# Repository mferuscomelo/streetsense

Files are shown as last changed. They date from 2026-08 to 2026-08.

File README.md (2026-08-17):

# StreetSense

*A submission for Hackster.io's [Modern Java in the Wild](https://www.hackster.io/contests/modern-java-in-the-wild) contest, sponsored by Avnet and Oracle.*

Know what you're breathing, everywhere you go, not just at home.

StreetSense demo video (https://youtu.be/7NOgXHcya4o)

## The story

### Why I built this

My apartment is thoroughly instrumented. Every room ties into my Home
Assistant setup, so I can tell you the CO2 level in my kitchen or the
humidity in my bedroom without thinking twice about it. It's a small
obsession of mine, but it means I always know exactly how good, or bad, the
air around me actually is.

Then I step outside for a run or a bike ride, and all of that knowledge just
disappears. I have no idea what I'm actually breathing, or how loud the
street I'm running down really is. A couple of my cycling friends have asked
me some version of "is it actually worth exercising outside today," and none
of us have ever had a real answer, just a weather app and a shrug.

I'm studying electrical engineering, so instead of leaving it at that, I
decided to build the answer myself. That's StreetSense: a sensor node small
enough to clip on before a run, paired with a phone that already goes
everywhere with you anyway.

### How it works

The sensor node measures particulate matter, volatile organic compounds, and
noise, once a second, and streams it to your phone over Bluetooth. You tag
the outing as a run, a ride, or a walk, and the app carries it through what I
call a session.

The interesting part isn't the raw numbers. Nobody thinks in micrograms per
cubic meter. So the backend turns a session into a dose: not "the air was 34
µg/m³ of PM2.5" but "you inhaled 0.6 mg of it, and the worst 30 seconds was
that one junction." It weighs the reading by how hard you were probably
breathing, since a jog through mediocre air costs you more than a walk
through the same air. Sessions stack up over time, so you can compare this
route against that one, or this morning against last week.

None of this needs your exact location. The app rounds every reading to a
grid cell about 110 meters wide before it sends anything, and your real
route never leaves your phone.

## System architecture

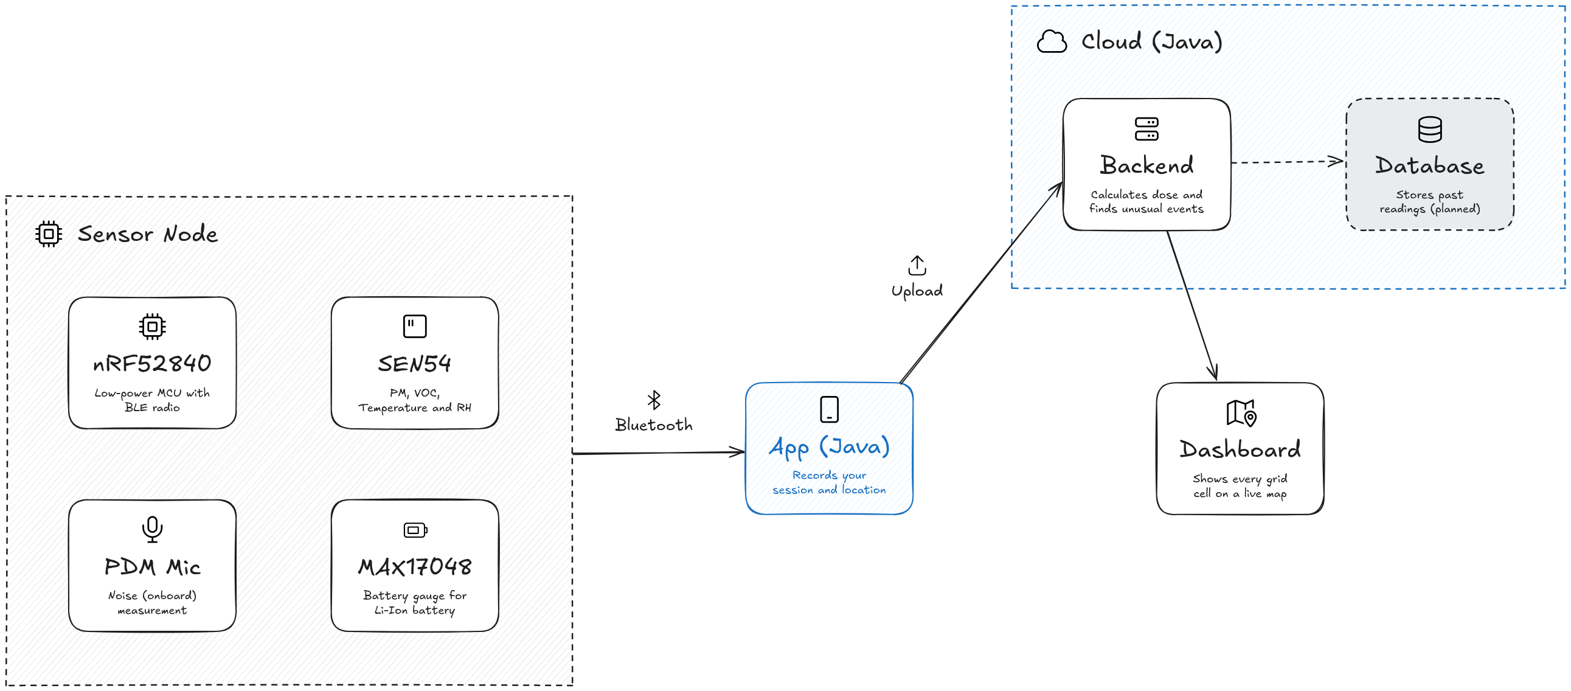
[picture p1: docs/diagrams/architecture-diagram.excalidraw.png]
StreetSense system architecture


StreetSense has four parts, and each one has exactly one job: the sensor
node measures, the app carries a session and protects your location, the
backend turns a reading into a dose and a verdict, and the dashboard shows
the crowd layer live. Each is broken out below with the specific hardware,
the communication protocols, and the reasoning behind each choice.

## Sensor node

A single board carries the whole sensing job, sampling once a second and
pushing every reading out over Bluetooth Low Energy. It has no idea what a
session or a dose is, it just measures and broadcasts. Keeping the firmware
this simple was deliberate: the only job it has is packing sensor values
into a fixed size packet, so there is nothing here that can drift out of
sync with what the app or the backend thinks a reading means.

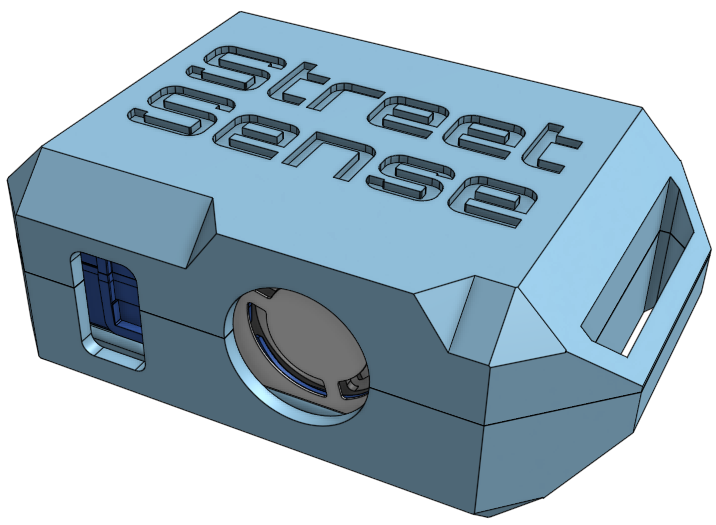
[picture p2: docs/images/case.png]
The sensor node's 3D printed case, designed in Onshape, showing the SEN54's inlet and fan outlet openings


The case is 3D printed and designed in Onshape alongside the internal
layout, with two separate openings for the SEN54 rather than one: the round
hole is the fan outlet, and the rectangular slot next to it is the air
inlet. Keeping them apart matters, Sensirion's own design guidance for this
sensor calls for the inlet and outlet to be sealed off from each other, so
outgoing air can't get pulled straight back in and thrown off the next
reading.

Here's what actually ended up inside it. It's a bit tight, but all the
electronics can be squeezed in:

<table>
<tr>
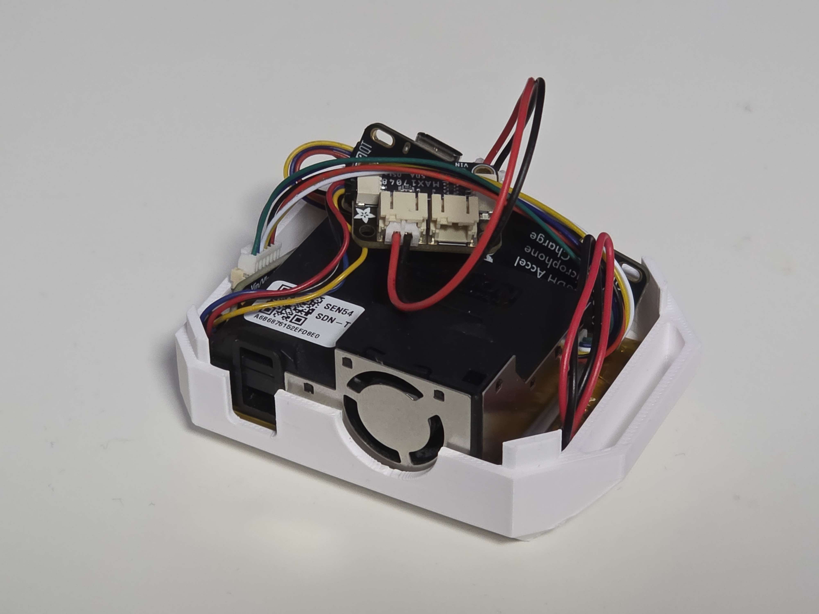
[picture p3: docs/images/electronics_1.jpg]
The sensor node's internals: SEN54, fuel gauge, and driver board wired together inside the open case
<td></td>
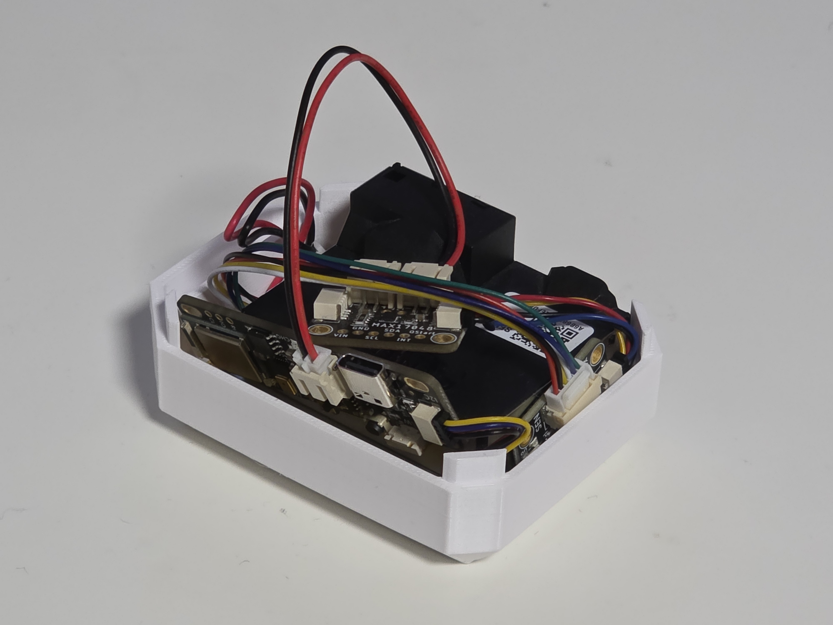
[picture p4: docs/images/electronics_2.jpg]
The sensor node's internals from a second angle, showing the battery and USB-C port
<td></td>
</tr>
</table>

And closed up, it looks like this:

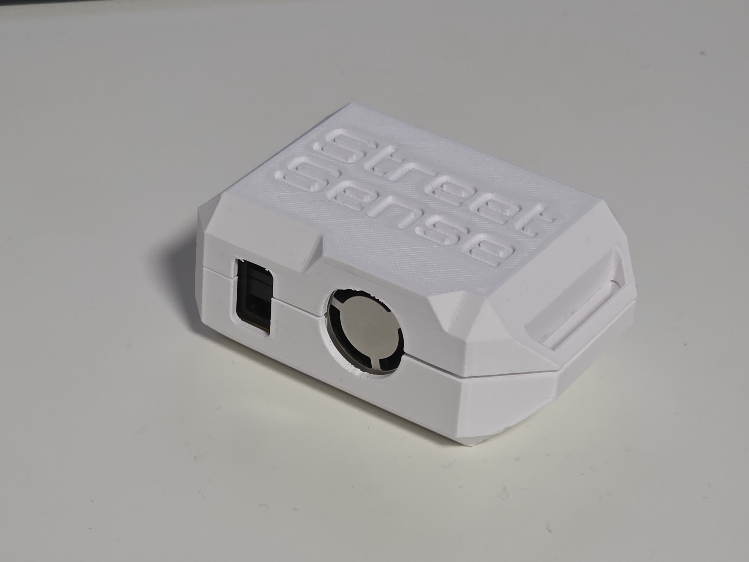
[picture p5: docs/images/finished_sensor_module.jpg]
The assembled sensor node, closed and labeled StreetSense


### Hardware

- **[Adafruit LED Glasses Driver, nRF52840](https://www.adafruit.com/product/5217)**
  is the MCU and BLE radio. Bluetooth Low Energy on this chip draws very
  little power, which matters on something running off a small battery, and
  the board happens to carry an onboard PDM digital microphone and an
  accelerometer too, so noise sensing needed no extra parts. It speaks BLE as
  a peripheral, and doubles as the I2C host for the two sensors below.
- **Sensirion SEN54** measures particulate matter (PM1, PM2.5, PM4, PM10),
  VOC index, temperature, and humidity. It connects over I2C (a simple two
  wire protocol many sensor chips use to talk to a microcontroller), via a
  STEMMA QT adapter breakout, a small keyed connector so the cable can't be
  plugged in backwards, at address `0x69`.
- The **onboard PDM digital microphone** picks up noise level, decoded on
  chip via PDM (pulse density modulation, a common way small digital
  microphones encode audio) through the nRF52840's own PDM peripheral.
- The **[Adafruit MAX17048 fuel gauge](https://www.adafruit.com/product/5580)**
  reports battery voltage, state of charge, and charge rate, also over I2C
  via STEMMA QT, at address `0x36`, sharing the bus with the SEN54 at a
  different address.
- A **2500 mAh, 3.7V LiPo cell** supplies power, wired to both the driver
  board's onboard charge circuit and directly across the MAX17048's sense
  leads.

The SEN54 needs its own driver to talk I2C correctly, checksums included, so
the firmware uses [Sensirion's own driver](https://github.com/Sensirion/arduino-i2c-sen5x)
for it rather than a hand rolled one, and Adafruit's own driver for the
MAX17048 for the same reason: reimplementing either from scratch would mean
redoing work already verified against this exact hardware, with no easy way
to check a hand written version except against the same hardware Sensirion
and Adafruit already tested theirs on. The firmware also runs the SEN54's
fan and laser scattering unit rather than its lower power mode without
particulate readings, since particulate matter is the entire reason this
sensor is here.

The noise figure comes from a flat, unweighted loudness reading off that
onboard microphone, converted to an approximate decibel figure using the
microphone's own datasheet sensitivity. There is no frequency weighting and
no calibration against a reference microphone, so it's better for comparing
one place or route against another than for a certified sound measurement.

Battery state of charge on the MAX17048 is a voltage curve estimate rather
than a precise coulomb count (tracking current in and out directly), and the
firmware treats it that way instead of presenting it as exact. The driver
board has no dedicated pin for detecting charging, so that state is inferred
from USB power being present together with a positive charge rate, and the
raw charge rate also rides along over Bluetooth so that inference can be
checked rather than taken on faith.

The 2500 mAh cell is the balance point for something worn while moving: big
enough to last a long outing without a recharge partway through, light
enough to still be worth clipping on before a run in the first place.

### Communication protocol

The node advertises a custom Bluetooth Low Energy GATT service, the
standard way two BLE devices agree on what their data looks like, with a
single notify characteristic: a named value the phone subscribes to once
and then receives automatically, once a second, without asking again. That
carries a fixed, packed binary packet, chosen over sending JSON text since
parsing JSON on a small microcontroller is unnecessary overhead once both
sides already agree on a fixed layout.

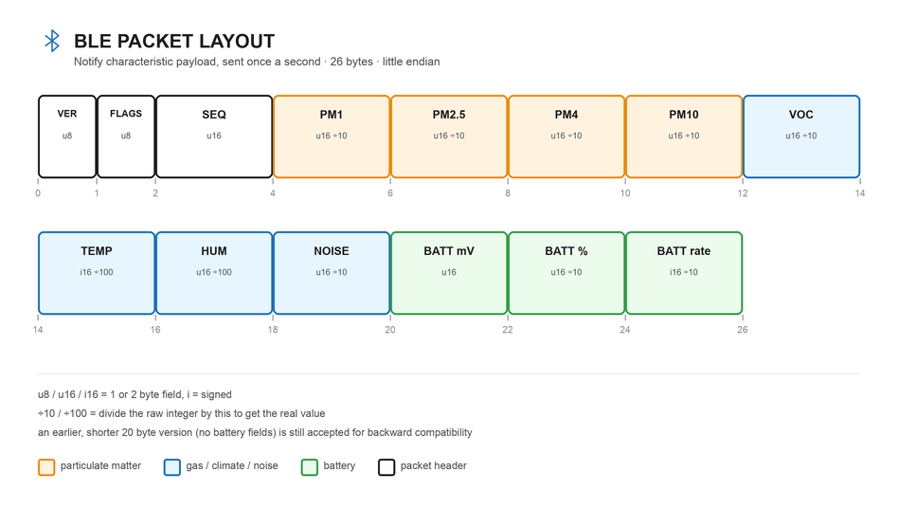
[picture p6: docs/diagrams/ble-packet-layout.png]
BLE packet layout, 26 bytes, little endian


The current wire format packs everything into 26 fixed size, fixed scale
bytes. An earlier, shorter 20 byte version was deliberately sized to fit
inside Bluetooth's default message size limit (called the MTU) so a
reading never needed to negotiate a larger one. Adding battery data needed
more room than that left, so the newer format spends the negotiation the
older one was built to avoid, and it carries a version number so the
backend can still read packets from older firmware without any special
handling. This exact layout is also checked byte for byte by matching tests
in the firmware, the app, and the backend, so if the three ever disagreed
about the format, a test would catch it before a device did.

### Firmware

The firmware is C++ via PlatformIO and the Arduino framework, not Java. A
JVM isn't a realistic option on a microcontroller this size within its
power and flash budget, and every hardware driver this project depends on,
for the radio, the microphone, and both I2C sensors, is C++ and Arduino
native. Java's role in this project is entirely in the backend, where it
has real preview features to show off.

## App

The Android app is the sensor node's only Bluetooth connection, and the
place your session actually lives. It scans for the node, connects, and
draws live values on screen once a second. It also owns the one privacy
critical step in this whole pipeline: before anything leaves your phone,
the app rounds your GPS position down to a grid cell about 110 meters wide.
Your exact route is drawn from a trace kept only on your phone, and it is
never uploaded.

<table>
<tr>
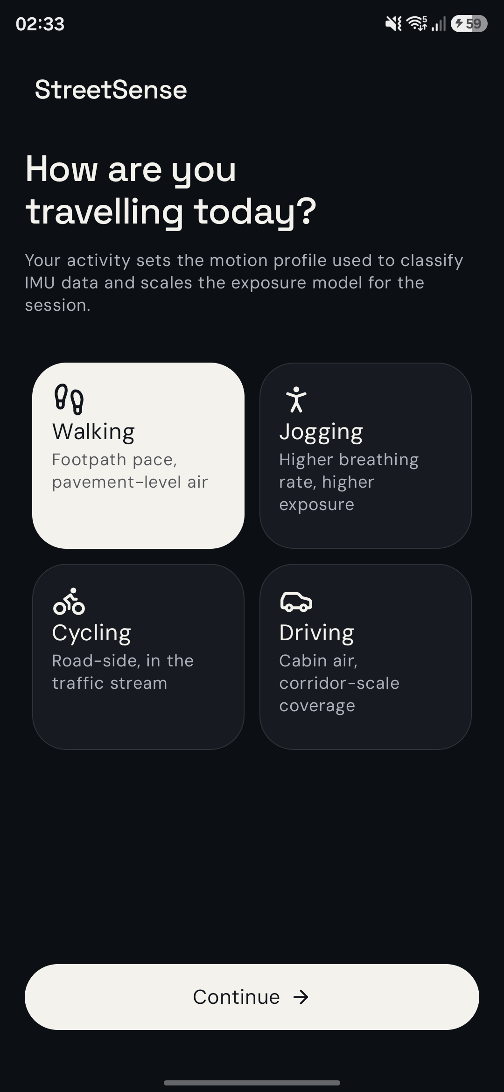
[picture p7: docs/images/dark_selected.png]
Activity picker screen
<td><br><sub>Pick your activity</sub></td>
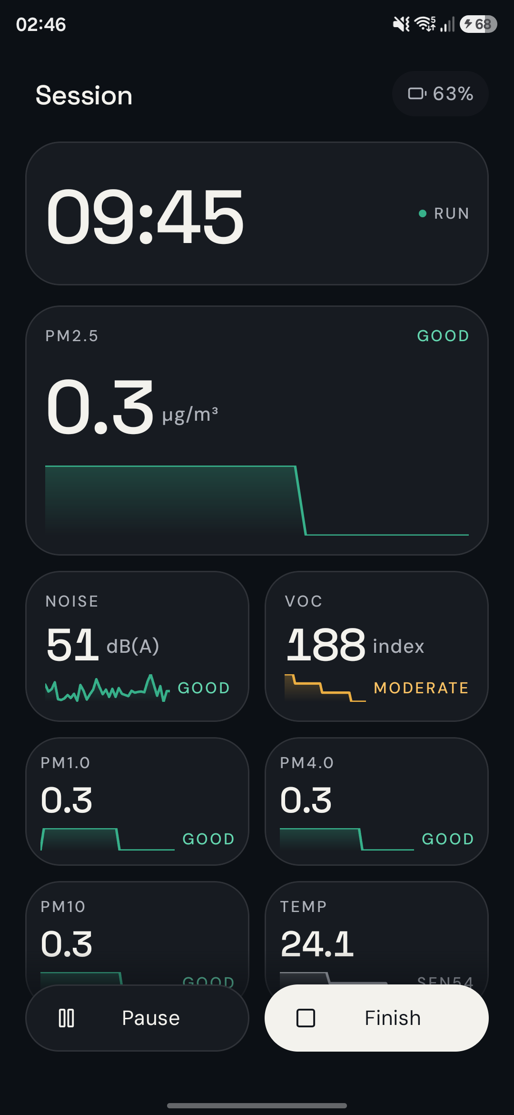
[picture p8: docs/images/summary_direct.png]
Live session screen
<td><br><sub>Live readings</sub></td>
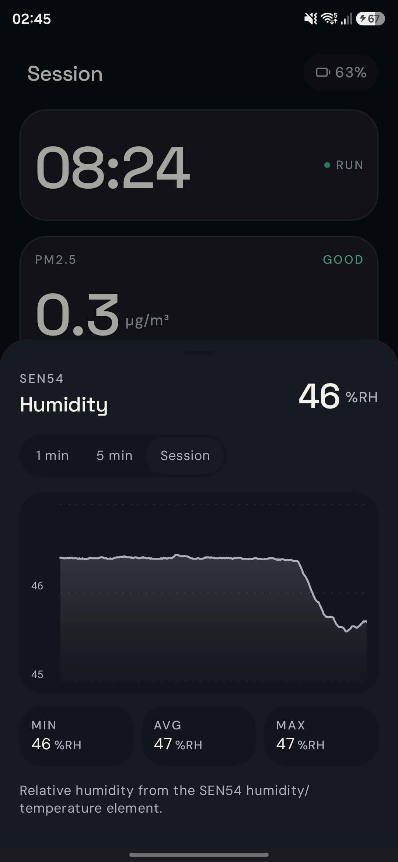
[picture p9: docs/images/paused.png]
Metric detail screen
<td><br><sub>Metric detail</sub></td>
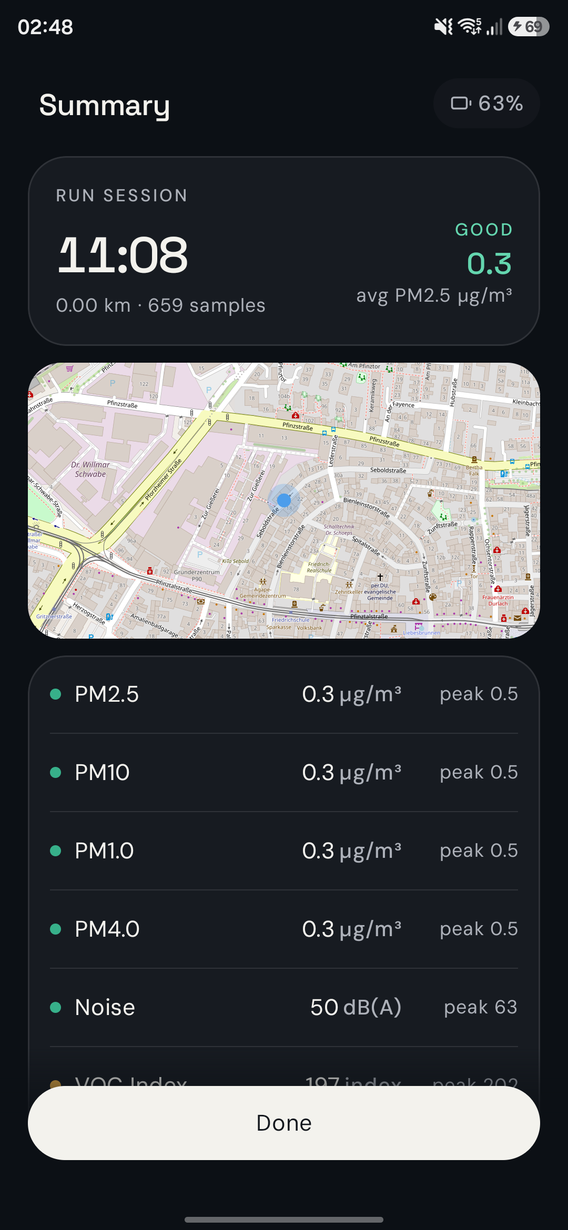
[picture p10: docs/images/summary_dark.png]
Session summary screen with route map
<td><br><sub>Session summary</sub></td>
</tr>
</table>

The app runs on Java 17 rather than Java 26, and that isn't a choice:
Android's own build tooling doesn't support anything newer yet. The
backend's Java 26 claim and the app's Java 17 ceiling are simply two facts
about two separate toolchains.

The app also only supports Android 12 and newer, which skips an entire
older branch of how Android used to handle Bluetooth permissions (older
versions asked for location permission just to scan for BLE devices,
current versions have dedicated Bluetooth permissions instead), a real
simplification at the cost of older phones.

The session map renders OpenStreetMap tiles through an open source library
rather than a commercial maps SDK, mainly so running the app doesn't need
an API key or a billing account, which matters for a project meant to be
cloned and run by someone else, not just demoed from one already configured
machine.

## Backend

This is where Java 26 lives, and where a raw reading turns into something a
person can actually act on. The build's toolchain declaration requires JDK
26, and a committed `build.log` file is the actual `java --version` output
from that exact toolchain, written automatically so the claim has a receipt
rather than resting on a version number in a config file.

Two preview features exist only in Java 26, and both do real work here, not
just a token appearance:

- **Structured Concurrency.** Every incoming reading kicks off three jobs at
  once: save it, update the rolling baseline, and check it for anything
  unusual. Structured Concurrency treats those three as a single unit of
  work. If one fails, they all fail together, so the system never ends up
  half updated with a reading saved but no baseline to match it.
- **Primitive types in patterns and switch.** Readings arrive as a mix of
  numeric types depending on the client. One exhaustive switch statement now
  handles all of them, replacing what used to be a small pile of
  `instanceof` checks.

There was a third Java 26 preview I tried and then dropped: Lazy Constants,
for one time grid setup. Once I actually wrote it out, a plain constant did
the exact same job with none of the complexity, so I cut it rather than keep
it around just to say I used it.

The rest of the backend leans on Java features that finalized a little
earlier, and gives the two preview features an actual domain to work in
instead of a toy demo:

- The **Foreign Function and Memory API** decodes the raw sensor packet
  coming off the firmware, matching its C struct layout field for field.
- **Scoped Values** bind session context once, so every job forked from
  Structured Concurrency can read it without threading it through every
  method call.
- **Stream Gatherers** compute the rolling per block baseline and the dose
  itself, both of which need to fold over a moving window, not just reduce
  a list.
- A **sealed interface** with exhaustive pattern matching classifies what
  actually changed in the air: a traffic spike looks different from smoke,
  which looks different from a solvent smell, and the code has to prove it
  handled every case. Every verdict carries the numbers it was decided
  from, so the reasoning can be checked against what is on screen rather
  than taken on faith.
- **Virtual threads** are what make forking three jobs per reading cheap
  enough to not matter under load.

It also turns a session's worth of readings into a dose, weighted by a
published ventilation multiplier per activity, and pools every
contributor's readings into a shared crowd layer, so a grid cell one person
has sampled once looks different from one a dozen people agree on.

Spring Boot is the only runtime dependency in the backend: no separate
database layer, template engine, or frontend build (more on that in
Dashboard below). Keeping that list short was deliberate for a Java
language contest, so the Java 26 features are doing the visible work
instead of a library doing it for them.

## Dashboard

The dashboard is served straight off the backend, with no separate service,
build step, or framework sitting in between: the same vanilla HTML, CSS, and
JavaScript that keeps the backend's own dependency list short, just applied
to the frontend half of the project too. It is the live public face of the
crowd layer, a fullscreen branded map that renders every grid cell colored
and sized by how much data backs it up, so a block one person sampled once
looks visibly different from one a dozen people agree on.

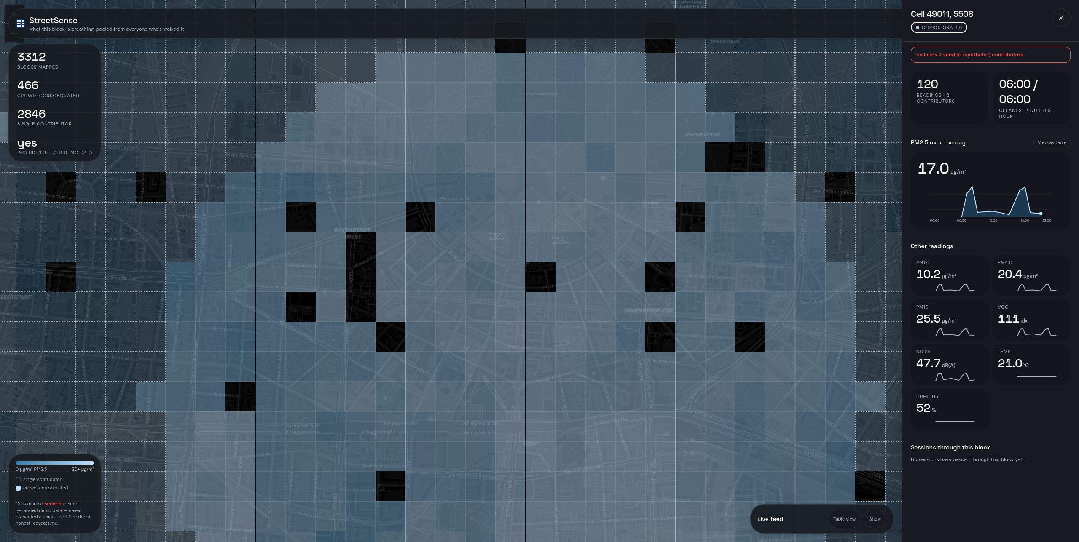
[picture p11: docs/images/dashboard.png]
The StreetSense dashboard: a fullscreen map of Karlsruhe tiled edge to edge with grid cells, and a cell detail panel open on the right showing pollutant readings, a PM2.5 chart, and session history


Confidence is drawn, not just labeled. A corroborated cell, the common case
across most of the grid, gets a solid hairline border and fills in at 50%
opacity; a single-contributor cell is still worth flagging as provisional,
so it keeps a dashed, more visible edge at a lighter 30%. Cells tile
edge-to-edge with no gaps between them, which took its own fix: a naive grid
stretches into rectangles away from the equator, since a degree of longitude
covers less real-world distance than a degree of latitude the further north
or south you go. Each cell's longitude span is widened by the same secant
correction Web Mercator's own projection applies, so a block reads as a true
square in real-world metres and, because that projection is conformal, in
pixels too, at any zoom level.

Clicking a cell opens a detail panel with everything the map's color alone
can't show: the full eight-channel pollutant breakdown, a PM2.5-over-the-day
chart with an hour-by-hour table view underneath it, the cleanest and
quietest hour recorded there, and the sessions that actually passed through
that specific block, scoped to the readings taken in that cell rather than
the whole route someone was on. A live feed at the bottom of the screen
lists readings as they arrive, with the same list-or-table toggle as the
chart above it.

Updates reach the page through Server Sent Events, a simple way for a
server to keep pushing new data to an already open web page without that
page repeatedly asking for it. Data only ever flows one direction here,
from backend to browser, so this fit without needing the two way machinery
of something like WebSockets, and Spring already has it built in, so no
extra library was needed to wire it up. A reading someone takes right now
shows up on screen without a page refresh.

## The bigger idea

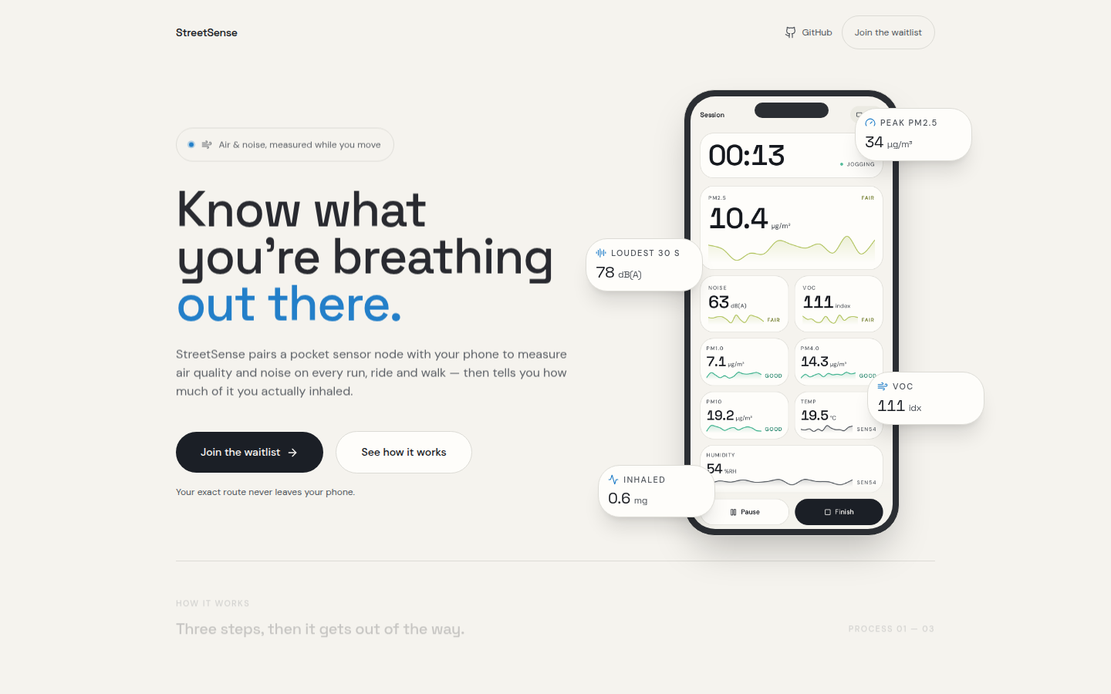
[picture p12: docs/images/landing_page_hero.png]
The Shared Map section of the StreetSense landing page


One sensor node answers one person's question. A few hundred of them in the
same city start answering everyone's.

Every reading gets pooled into a shared map, built from grid cells rather
than exact coordinates, so a street your phone has never walked down can
still show a result, because somebody else's phone already has. The
dashboard even shows the difference between a block one person sampled once
and one that a dozen people agree on, so you can see how much to trust it.

Compare that to how cities check air quality today: a handful of expensive,
fixed reference stations, each covering a tiny radius, updating once an
hour, and standing exactly still. StreetSense flips that. The readings are
individually noisier, but there are thousands of them, moving, updating
live, and covering the actual streets people use instead of the streets a
monitoring budget could afford.

At real scale, that stops being a fitness app and starts being a live,
street level dataset that doesn't exist anywhere today, built by the people
who are already outside instead of a fleet of hardware a city would have to
buy and maintain. Researchers get an exposure signal instead of a nearest
station guess. City planners can point at the exact junction that needs a
fix, not just the general neighborhood. And every single contributor still
gets the thing that got them to install the app in the first place: whether
today is actually worth running outside for, and which way to go.

[streetsense.tech](https://streetsense.tech/) has more on where this project is headed, plus a waitlist if you would like early access.

## Limits

I'd rather list what this doesn't do than have someone discover it later.

- The SEN54 is a consumer sensor, not lab equipment. It's good for comparing
  a place against its own history, not for a medical or regulatory claim.
- The noise reading has no frequency weighting filter and no per unit
  calibration, so it's not a certified sound level measurement. Use it to
  compare one route to another, not to argue a legal decibel limit.
- The event classifier runs on fixed rules over real sensor cross products,
  not a trained model, and every decision it makes shows the exact numbers
  it was based on.
- Dose is a population level estimate. It doesn't know your fitness level or
  your actual breathing rate, only a published ventilation multiplier for
  your activity type.

## Next steps

A few friends have already been taking this out on actual runs and rides,
and the feedback so far has been encouraging enough that this doesn't feel
like a project that ends at the submission deadline. There's a lot more
room to grow here:

- A real Postgres database, so the backend can keep more than a short
  rolling window of readings.
- Offline buffering on the app, so a dropped connection doesn't just lose a
  reading.
- Motion tagging from the onboard accelerometer, to tell a stationary
  reading apart from one taken mid stride, which matters most for noise.

I plan to keep building on this after the contest wraps up, since the idea
has more potential than a couple of weeks can show. If you're reading this
well after the submission date and the repository has moved on from what's
described here, that's why. It would be a shame to stop now.

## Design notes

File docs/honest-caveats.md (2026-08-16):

# Honest caveats

What this project does and doesn't claim, stated plainly rather than left
to be discovered.

- **The SEN54 is a consumer PM/VOC *proxy*, not a lab-grade reference
  instrument.** Its readings are useful for relative comparison (this
  block vs. its own history) and not suitable for regulatory or medical
  claims. The firmware's real sensor path (`ledglasses_sen54` environment,
  `firmware/src/sen54_sensor_source.cpp`) has been run end-to-end against
  physical hardware: real SEN54, PDM mic, and MAX17048 fuel gauge, over
  BLE to the app. `ledglasses` (the default environment) still runs a
  synthetic source for demos without the sensor attached; see
  `docs/ble-protocol.md` for how synthetic data is flagged end-to-end.
- **The noise figure is an uncalibrated estimate, not a certified dB(A)
  measurement.** `firmware/src/pdm_noise_meter.cpp` computes a flat
  (unweighted) RMS level from the onboard PDM microphone and applies a
  datasheet sensitivity offset. There is no A-weighting filter and no
  per-unit calibration against a reference source. It over-reports
  low-frequency energy (traffic rumble, wind) relative to a real sound level
  meter, and its absolute value carries a few dB of uncalibrated error. This
  is adequate for what StreetSense does with it, comparing a place against
  its own history, and one route or hour against another, where a
  consistent offset cancels out, and is not adequate for any absolute claim
  ("this street is above X dB"). No such claim is made anywhere in this
  project. See `firmware/src/pdm_noise_meter.h` for the full accounting.
- **Classification is rule-based, over sensor cross-products, not a
  trained model.** Two layers, both explicit thresholds:
  - The rolling per-`(cell, hour)` baseline (Stream Gatherers computing an
    EWMA-smoothed mean/stddev per pollutant) is the same mechanism this
    project has shipped from the start.
  - The event classifier (`backend/.../anomaly/AnomalyDetector.java`) reads
    the *combination* of which channels rose (particulates alone,
    particulates with VOC, VOC alone, or noise alone) rather than reporting
    a bare severity. This is still a fixed decision table, not a model, and
    every verdict carries the z-scores it was decided from
    (`domain/Evidence.java`) specifically so the reasoning can be checked
    against the numbers on screen rather than taken on faith.
- **Only rises are flagged as anomalies.** Air measurably cleaner than a
  block's own history reads as `Normal`, not as an event; the detector
  keys off a positive z-score, not `|z|`.
- **Dose is a population-level estimate, not a personal one.**
  `backend/.../domain/Activity.java` weights concentration by a fixed
  ventilation multiplier per activity (walk/cycle/run), derived from
  published ratios of typical minute ventilation to resting ventilation.
  This is meant to make one session comparable to another (a run is
  reported as costing more than a walk through identical air, which is true
  in aggregate), not to estimate any individual's actual intake, which
  depends on fitness, pace, and physiology this project does not measure.
- **The precise GPS trace never leaves the phone.** The app snaps every
  reading to a `~110m` grid cell (`domain/GridCell.java`, mirrored in
  `app/.../location/GridCell.java`) before uploading; the backend's
  `DecodedReading` has no latitude/longitude field to receive one into. The
  session map in the app is drawn from the phone's own local trace
  (`app/.../session/TracePoint.java`), which is never uploaded and never
  leaves the device. A submission from an app build that predates this
  split (posting `lat`/`lon`) is rejected with an HTTP 400 rather than
  silently re-snapped server-side; see `ReadingControllerTest`.
  - The `~110m` cell size is a deliberate trade, not an arbitrary constant:
    finer cells give better route resolution but weaker anonymity; coarser
    cells give better anonymity but can't distinguish one street from the
    next. See the constant's own documentation in `GridCell.java`. A cell is
    `~110m` on a side at any latitude, not just at the equator — the
    longitude bucket widens by `1 / cos(latitude)` so real-world cell width
    keeps pace with latitude's fixed ~110m instead of shrinking toward the
    poles.
- **Contributor identity is a random per-install id, not a device or
  account identifier.** `app/.../session/ContributorId.java` generates a
  UUID stored in app-local preferences, not `ANDROID_ID`, not an
  advertising id, nothing derived from hardware or an account. It exists
  solely so the crowd layer can distinguish contributors and report
  `contributorCount` honestly; it correlates with nothing else, and
  clearing app data yields a new one with no other consequence.
- **Seeded contributors are always flagged, never presented as measured.**
  The crowd layer can be demonstrated with a single physical node by
  generating additional contributors (`ContributorSeeder`, off unless
  `streetsense.seed.enabled=true`). Every seeded contributor id carries the
  `seed:` prefix and every seeded reading sets the synthetic-data flag, so
  `CellSummary.seededContributorCount` and `mock` report this separately in
  every API response: the same discipline `FLAG_MOCK_DATA` applies to
  synthetic sensor readings, applied one level up to synthetic
  *contributors*.
- **A verdict is only as good as the evidence behind it, and every response
  says how much there is.** `CellStats.contributorCount` and
  `CellSummary.confidence()` distinguish "many readings from one person"
  from "corroborated by more than one contributor". The crowd map and the
  live verdict both carry this, so a cell sampled once looks different from
  a cell twelve people agree on, rather than the same colour.
- **This is a distributed sensing network, not a mesh.** Each phone talks
  directly to the backend; nodes don't relay for each other. "Mesh" is not
  used to describe this system anywhere in the docs.
- **Synthetic data is always flagged.** `FLAG_MOCK_DATA` on the wire, a
  badge in the app UI, and a `mock` field in every backend API response;
  see `docs/ble-protocol.md`. Nothing in this system can present synthetic
  data as measured data without that flag being visible.

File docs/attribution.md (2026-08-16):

# Third-party materials

Every third-party component this project depends on, and the licence it
carries. The contest rules are strict about third-party materials, so this is
listed explicitly rather than left to be inferred from lockfiles.

## Firmware

| Component | Licence | Why it's here |
|---|---|---|
| [Sensirion I2C SEN5X](https://github.com/Sensirion/arduino-i2c-sen5x) `0.3.0` | BSD-3-Clause | Sensirion's own driver for the Sensirion SEN54. Hand-rolling the I2C command set and its CRC-8 would be a worse engineering decision and an untestable one, since this project has no way to verify a hand-written driver except against the same hardware the official one already supports. |
| Sensirion Core `0.7.3` | BSD-3-Clause | Transitive dependency of the SEN5X driver. |
| [Adafruit MAX1704X](https://github.com/adafruit/Adafruit_MAX1704X) `1.0.3` | BSD | Adafruit's own driver for the MAX17048 fuel gauge on their 5580 breakout, for the same reason as the SEN5X driver above. |
| Adafruit BusIO | MIT | Transitive dependency of the MAX1704X driver (shared I2C register helpers). |
| Adafruit nRF52 Arduino core (Bluefruit BLE stack, `PDM` library) | LGPL-2.1 / BSD, per component | Ships bundled with the board's framework package; unavoidable for any Arduino-framework build on this board. Used as a library, unmodified, and not redistributed in source form. |

The SEN5X driver, Sensirion Core, MAX1704X driver, and BusIO are fetched by
PlatformIO at build time from their published packages; see
`firmware/platformio.ini`. They are not vendored into this repository.

## Android app

| Component | Licence | Why it's here |
|---|---|---|
| [osmdroid](https://github.com/osmdroid/osmdroid) | Apache-2.0 | OpenStreetMap tile rendering for the session map. Chosen over the Google Maps SDK specifically to avoid an API key, a billing account, and proprietary tile terms. |
| OpenStreetMap tile data | ODbL 1.0 | Map data © OpenStreetMap contributors. Attribution is rendered on-map by osmdroid and repeated in the app's about screen. |

## Backend

Spring Boot and the JDK itself. No other runtime dependencies.

## What is *not* third-party

The BLE wire protocol, the packet encoder, the FFM decoder, the grid and
baseline model, the event classifier, the session model, and all firmware
outside the SEN5x driver are original to this project.

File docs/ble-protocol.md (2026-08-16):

# BLE protocol

StreetSense sensor nodes advertise a custom GATT service with a single notify
characteristic carrying a fixed 26-byte packet, chosen over a Nordic UART +
JSON approach for a concrete reason: JSON parsing on a Cortex-M4 microcontroller
is unnecessary overhead, and a packed binary struct keeps both sides simple.
(v1 was 20 bytes, sized to avoid MTU negotiation entirely; see the wire
format section below for why v2 spent that budget.)

## Identifiers

| | UUID |
|---|---|
| Device name | `StreetSense-01` |
| Service | `ee8ebcc5-07f5-4bce-96c2-ccafc2a91f7c` |
| Characteristic (notify) | `b70d5d1b-481e-4d17-8f6d-6b91b22d6b60` |

Defined once in `firmware/include/ble_uuids.h` and mirrored in
`app/.../ble/BleScanner.java` / `SensorNodeClient.java`. If either side's
values drift, the app will simply never find the node, so get them from that
header, don't retype them.

**Adafruit Bluefruit gotcha**: on the firmware side, `BLEService`/
`BLECharacteristic` take 128-bit UUIDs as a byte array in **LSB-first
(reversed)** order. Get this backwards and the service is silently
unadvertised, no error raised. `ble_uuids.h` documents both the MSB-first
UUID string (for cross-referencing against the app/backend) and the
already-reversed byte array Bluefruit actually needs. Android's
`UUID.fromString(...)` takes the normal MSB-first form, no reversal there.

## Wire format: exactly 26 bytes (v2)

v1 was 20 bytes, deliberately sized to fit inside the default BLE ATT MTU of
23 bytes (20-byte payload + 3-byte L2CAP/ATT header) so a notification never
needed MTU negotiation. Adding battery telemetry (v2) needed more room than
that budget had left, so v2 spends the negotiation v1 was built to avoid:
firmware calls `Bluefruit.configPrphBandwidth(BANDWIDTH_MAX)` before
`Bluefruit.begin()` (raising the peripheral's MTU ceiling to 247), and the
app requests a 64-byte MTU on connect (`SensorNodeClient.REQUESTED_MTU`)
before discovering services. `version` is what signals the change: the
backend's decoder is version-aware and still accepts v1's 20-byte packets
from older firmware.

All multi-byte fields are little-endian.

| Offset | Field | Type | Scale | Notes |
|---|---|---|---|---|
| 0 | `version` | u8 | n/a | schema version, currently `2` |
| 1 | `flags` | u8 | n/a | bit0 = `FLAG_MOCK_DATA` (flags a synthetic reading), bit1 = `FLAG_CHARGING`, bit2 = `FLAG_BATTERY_VALID` |
| 2 | `seq` | u16 | n/a | wraps; detects dropped notifications |
| 4 | `pm1` | u16 | ÷10 | ug/m³ |
| 6 | `pm2_5` | u16 | ÷10 | ug/m³ |
| 8 | `pm4` | u16 | ÷10 | ug/m³ |
| 10 | `pm10` | u16 | ÷10 | ug/m³ |
| 12 | `voc_index` | u16 | ÷10 | unitless VOC index |
| 14 | `temp_c` | i16 (signed) | ÷100 | °C |
| 16 | `humidity` | u16 | ÷100 | %RH |
| 18 | `noise_db` | u16 | ÷10 | dB(A) |
| 20 | `batt_mv` | u16 | n/a | millivolts; 0 when `FLAG_BATTERY_VALID` is clear |
| 22 | `batt_soc` | u16 | ÷10 | battery percent, 0 to 100; 0 when invalid |
| 24 | `batt_rate` | i16 (signed) | ÷10 | %/hour; negative while discharging; 0 when invalid |

Total: 26 bytes. See `docs/golden-packet.md` for concrete byte-for-byte
examples (both v1 and v2) independently reproduced by the firmware, Android,
and backend test suites.

### Battery telemetry

Battery data comes from an Adafruit MAX17048 fuel gauge (STEMMA QT breakout,
product 5580) sharing the I2C bus with the SEN54 at a different address
(`0x36` vs `0x69`). Its state of charge is a ModelGauge voltage-curve
estimate, not a coulomb count; see the honesty note in
`firmware/lib/battery_monitor/battery_monitor.h`.

The nRF52840 has no charger-status pin exposed on this driver board, so
`FLAG_CHARGING` is inferred rather than read directly: USB VBUS detected
(`NRF_POWER->USBREGSTATUS`) **and** the gauge's own charge rate is positive
past a small noise floor. The raw signed `batt_rate` also goes out on the
wire, so that inference is auditable rather than hidden.

If the gauge never starts (missing hardware, I2C fault), the node keeps
advertising and notifying. `FLAG_BATTERY_VALID` just stays clear and the
three battery fields go out as zero, the same "present but honest" pattern
the SEN54 path uses for a missing sensor.

## Version authority

The phone app forwards these bytes **verbatim**, base64-encoded, alongside
a grid cell, hour of day, session id, and activity, rather than re-deriving
a decoded JSON object. The backend, via the Foreign Function & Memory API
(`backend/.../wire/PacketLayout.java`), is the sole authority on decoding.
`PacketLayout.decode()` dispatches on packet length (20 or 26 bytes) and the
`version` byte, so a v1 node's packets still decode correctly even after the
backend has moved on to understanding v2. The app's own subset decoder
(`app/.../ble/SensorPacket.java`) accepts either length too, treating
anything shorter than the v2 layout as simply having no battery data. That
duplication between the app's decoder and the backend's is real and
intentional, not eliminated, just kept minimal.

Note what is *not* forwarded: raw GPS. The phone snaps its fix to the grid
cell before uploading and keeps the precise trace to itself; see
`docs/honest-caveats.md` for why.

## Honesty mechanism

`FLAG_MOCK_DATA` is set on every packet produced by the firmware's synthetic
sensor source, `firmware/lib/mock_sensor_source/mock_sensor_source.cpp`, used
for demos without a physical sensor attached. The app surfaces this as a
badge in the UI, and the backend passes a `mock` field through every API
response. Neither is optional: no judge or user should be able to mistake a
synthetic reading for a real one. Battery telemetry is real on both firmware
environments regardless of this flag; the physical MAX17048 is composed onto
the reading independently of which environmental sensor source, synthetic or
SEN54, produced the rest of the packet.

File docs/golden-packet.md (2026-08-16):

# Golden packet fixtures

Canonical `StreetSensePacket` values, used verbatim by three independent test
suites:

- `firmware/test/test_packet/test_packet.cpp` (Unity)
- `app/src/test/java/io/streetsense/app/SensorPacketTest.java` (JUnit)
- `backend/src/test/java/io/streetsense/backend/wire/PacketLayoutTest.java` (JUnit + FFM)

Each suite hardcodes the same byte arrays independently, since there's no
shared build system across PlatformIO/Gradle-Android/Gradle-backend to import
a common file from. Agreement is proven by all three decoders producing the
same field values from the same bytes: if firmware, Android, and the backend
ever disagree on the wire format, one of these three tests catches it.

Generated via Python's `struct.pack(...)` to avoid any floating-point
rounding ambiguity between languages. The bytes below are exact, not derived
by encoding floats through each language's own scaling logic.

## v2, 26 bytes

`struct.pack('<BBHHHHHHhHHHHh', 2, 0x07, 42, 83, 157, 192, 246, 1345, 2137, 5280, 584, 3897, 875, 123)`

```
0x02, 0x07, 0x2A, 0x00, 0x53, 0x00, 0x9D, 0x00, 0xC0, 0x00,
0xF6, 0x00, 0x41, 0x05, 0x59, 0x08, 0xA0, 0x14, 0x48, 0x02,
0x39, 0x0F, 0x6B, 0x03, 0x7B, 0x00
```

| Field | Raw (u16/i16) | Scale | Decoded value |
|---|---|---|---|
| `version` | 2 | n/a | `2` |
| `flags` | 0x07 | n/a | `FLAG_MOCK_DATA` (synthetic reading) \| `FLAG_CHARGING` \| `FLAG_BATTERY_VALID` all set |
| `seq` | 42 | n/a | `42` |
| `pm1` | 83 | ÷10 | `8.3` ug/m³ |
| `pm2_5` | 157 | ÷10 | `15.7` ug/m³ |
| `pm4` | 192 | ÷10 | `19.2` ug/m³ |
| `pm10` | 246 | ÷10 | `24.6` ug/m³ |
| `voc_index` | 1345 | ÷10 | `134.5` |
| `temp_c` | 2137 (signed) | ÷100 | `21.37` °C |
| `humidity` | 5280 | ÷100 | `52.80` %RH |
| `noise_db` | 584 | ÷10 | `58.4` dB(A) |
| `batt_mv` | 3897 | n/a | `3.897` V |
| `batt_soc` | 875 | ÷10 | `87.5` % |
| `batt_rate` | 123 (signed) | ÷10 | `+12.3` %/hour (charging) |

## v1, 20 bytes (no battery telemetry)

`struct.pack('<BBHHHHHHhHH', 1, 1, 42, 83, 157, 192, 246, 1345, 2137, 5280, 584)`

Same environmental values as the v2 fixture above, byte-identical to the
first 20 bytes of it minus the flags byte (v1 has no `FLAG_CHARGING` /
`FLAG_BATTERY_VALID` bits to set).

```
0x01, 0x01, 0x2A, 0x00, 0x53, 0x00, 0x9D, 0x00, 0xC0, 0x00,
0xF6, 0x00, 0x41, 0x05, 0x59, 0x08, 0xA0, 0x14, 0x48, 0x02
```

Decodes with the same environmental fields as above, `version = 1`,
`flags = FLAG_MOCK_DATA` only (a synthetic reading), and battery telemetry
absent (backend `DecodedPacket.battery() == BatteryStatus.ABSENT`; app
`SensorPacket.batteryValid() == false`). Kept as a fixture to prove the
decoders stay backward-compatible with nodes still running v1 firmware.

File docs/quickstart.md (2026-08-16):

# Quickstart

This guide explains how to build and run each part of StreetSense. Each part
has a one command runner script in [`scripts/`](../scripts/). Each section
below also shows the full command behind the script, as proof of what runs.

## Firmware

The firmware has two build targets. Both targets share the same code. Only
the sensor source file changes.

Run the host side tests:

```sh
scripts/run-firmware.sh test
```

Build the synthetic sensor target. This target always flags its data as
synthetic:

```sh
scripts/run-firmware.sh
```

Build the real sensor target. This target uses a real SEN54 sensor, a real
microphone, and a real battery gauge:

```sh
scripts/run-firmware.sh build-sen54
```

Upload the firmware to the board. Note that this step erases the board's
current firmware:

```sh
scripts/run-firmware.sh flash
```

Watch the sensor packets over the serial connection:

```sh
scripts/run-firmware.sh monitor
```

The `ledglasses` target is the default target. The `ledglasses_sen54` target
uses real hardware. Both targets have run over Bluetooth against the app and
the backend.

## Backend

Run the backend:

```sh
scripts/run-backend.sh
```

Run the backend with seeded crowd data:

```sh
scripts/run-backend.sh --seed
```

The backend needs a Java 26 build tool. The script installs this tool
automatically.

Open `http://localhost:8080` to view the dashboard. The dashboard updates in
real time.

The `--seed` flag adds fake contributors to the crowd layer. Use this flag to
show the crowd layer with only one real sensor node. The system always marks
seeded contributors as seeded. It never shows seeded data as real data. See
[`docs/honest-caveats.md`](honest-caveats.md) for more detail.

## App

The app needs a real phone. Bluetooth does not work in the Android emulator.

Run the app:

```sh
scripts/run-app.sh
```

This script sets up `local.properties`. It then runs `adb reverse tcp:8080
tcp:8080`. It then builds the app and installs it on your connected phone.

Complete these three steps before you run the app:

1. Turn on USB debugging on your phone. Open Settings, then About, then tap
   the build number seven times. Open Developer Options. Plug in your phone.
   Accept the RSA prompt.
2. Point the app at your backend. Check that `MainActivity.BACKEND_BASE_URL`
   and `res/xml/network_security_config.xml` list the same host. The script
   uses `adb reverse tcp:8080 tcp:8080` with `http://localhost:8080`. This
   setup survives network changes.
3. Turn on Location at the system level. Grant Precise location, not
   Approximate location. A coarse location cannot fit inside a 110 meter
   grid cell.

Open the app. Pick an activity. Tap Continue. Connect to `StreetSense-01`.
Tap Start session. The screen shows live values once per second. A badge
appears when the connected sensor node sends synthetic data. Tap Finish to
see your session summary.

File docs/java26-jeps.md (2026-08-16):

# Java 26 and modern-Java feature map

**Java 26 runs on the backend JVM only.** Android's build toolchain caps
`sourceCompatibility`/`targetCompatibility` at Java 17 (see
[developer.android.com/build/jdks](https://developer.android.com/build/jdks)),
so `/app` is Java 17 on purpose, and every claim below is about `/backend`.
Proof: `backend/build.gradle.kts`'s `JavaLanguageVersion.of(26)` toolchain
declaration, plus the committed `build.log` at the repo root
(`java --version` output from the actual toolchain used to build).

Each feature below gets one line of *why this project actually wants it*.
The point of this document is to make the case that these features are a
coherent design, not a checklist assembled for rubric points. If any one of
these ever reads as strained, the honest move is to drop it, not defend it.

## Java-26-specific (preview, requires `--enable-preview`)

Three of the JEPs below are previews unique to JDK 26: these are the parts
of this project that couldn't have been written against JDK 24 or 25.

### JEP 525, Structured Concurrency (6th preview)
**Where:** `backend/.../ingest/IngestService.java`
**Why:** One ingested reading fans out into persist / update-baseline /
anomaly-check as a single unit of work with one lifetime. If any subtask
fails, the whole ingest fails together instead of leaving the system
half-updated (e.g. a reading stored but no baseline update, silently
skewing future anomaly checks). `StructuredTaskScope.open()` + `fork()` +
`join()` is a direct, honest fit for "these three things either all
succeed or the request fails."

**Considered and declined a second time:** the crowd merge
(`backend/.../crowd/CrowdService.java`) was a candidate for a second
`StructuredTaskScope` site, per-hour lookups fanned out across a cell.
Written out, it was ceremony around a handful of in-memory map reads that
don't block; forking buys nothing a plain loop doesn't already have. The
honest move for a strained feature is to drop it, not defend it, so it's
dropped, see the comment on `CrowdService` for the reasoning. A
Postgres-backed repository would change that calculus, since the per-cell
aggregations would become independent queries actually worth fanning out.

### JEP 530, Primitive Types in Patterns, `instanceof`, and `switch` (4th preview)
**Where:** `backend/.../web/LenientJson.java`
**Why:** Ingest JSON fields legitimately arrive as different boxed types
across client versions: a whole-number JSON value deserializes as
`Integer`, a fractional one as `Double`, and some client code stringifies
numbers to dodge float-precision quirks. `case int i -> i; case double d ->
d; case String s -> Double.parseDouble(s);` replaces a chain of
`instanceof` checks with one exhaustive expression, the textbook scenario
the JEP itself cites.

### JEP 526, Lazy Constants (2nd preview)
**Status: dropped.** The intended use (one-time grid configuration init)
didn't clear the bar of "would this project use it without the contest"
once written out: a plain static final field already does the job with no
meaningful startup-order subtlety to justify `StableValue`. Rather than
contrive a use, this is left out, though a genuine lazy-init need could
revive it later, for instance an expensive HTTP/3 reference-station client
(see JEP 517 below).

## Modern Java, final in earlier releases (22-25)

These aren't Java-26-specific claims on their own, they're finalized
features this project uses because they're the right tool, and they give
the three preview features above a real domain to operate on rather than a
standalone demo.

### FFM API, `MemoryLayout` + `VarHandle` (final in 22)
**Where:** `backend/.../wire/PacketLayout.java`
**Why:** A packed little-endian C struct crossing into Java is the textbook
FFM use case. The `StructLayout` mirrors `firmware/.../packet.h`
field-for-field, so the two stay legible against each other with no
hand-computed byte offsets. One non-obvious wrinkle documented in the code:
a struct-level `withByteAlignment(1)` is rejected by the JDK
(`IllegalArgumentException: Invalid alignment constraint`) because a group
layout's alignment can't go below its strictest member's natural alignment,
so each `JAVA_SHORT` field needs its own `.withByteAlignment(1)` override to
actually reproduce `#pragma pack(1)`.

### Scoped Values (JEP 506, final in 25)
**Where:** `backend/.../ingest/IngestContext.java`, bound in `IngestService`
**Why:** JEP 525 specifies that structured-concurrency subtasks inherit
`ScopedValue` bindings from the thread that forked them. Binding an
`IngestContext` (node id, correlation id) once at the top of `ingest()`
means all three forked subtasks read it without threading it through every
method signature. This is what makes the structured-concurrency usage read
as a deliberate pairing rather than two unrelated features used side by
side.

### Stream Gatherers (JEP 485, final in 24)
**Where:** `backend/.../baseline/RollingBaseline.java`,
`backend/.../baseline/EwmaGatherer.java`,
`backend/.../session/DoseGatherer.java`,
`backend/.../session/SessionSummariser.java`
**Why:** The rolling per-`(cell, hour)` baseline is the feature the "AI"
claim rests on, and a sliding window over recent readings is literally what
`Gatherers.windowSliding(n)` is for. A custom `Gatherer` folds those windows
into one running EWMA-smoothed value, so a single noisy reading nudges the
baseline instead of replacing it outright.

A later addition brought two more Gatherer uses with genuinely different
shapes, not restatements of the first: `DoseGatherer` is a stateful fold
where each reading's contribution depends on the *gap* to the reading
before it (inhaled dose accumulates over elapsed time, not reading count),
which `reduce` cannot express without external state. `SessionSummariser`
reuses `Gatherers.windowSliding` a second time, over a session's own
readings, to find the worst 30-reading stretch of a run rather than only a
session-wide mean, the same primitive, applied to a genuinely different
question ("where was it worst" vs. "what is normal here").

### Sealed interface + records + exhaustive switch
**Where:** `backend/.../domain/Verdict.java`,
`backend/.../web/VerdictView.java`
**Why:** `Verdict` was originally `Normal | Elevated | Spike`, a severity
scale with no semantics, closed by `sealed interface ... permits`. It is now
`Normal | TrafficPlume | SmokeOrExhaust | Solvent | LoudButClean`: the
detector already computed z-scores for particulates, VOC, and noise, and the
old version discarded two of them in favour of whichever was largest. The
*combination* of which channels moved is the actual diagnosis: particulates
alone reads as road dust, particulates with VOC as combustion, VOC alone as
solvent, noise alone as loud-but-clean air.

Switching over the sealed hierarchy needs no `default` branch: adding a
sixth diagnosis is a compile error at every site that must handle it, and
`VerdictView.of` (which turns a verdict into the sentence the app shows,
e.g. *"Fumes are 18.0x the usual spread here with particulates untouched"*)
is where that constraint is actually exercised, not just claimed. This is
also what gives the JEP 530 primitive-pattern switch a real, non-trivial
domain model to sit beside.

### Virtual threads
**Where:** `backend/src/main/resources/application.yml`
(`spring.threads.virtual.enabled: true`)
**Why:** One line, and it's what makes fork-per-subtask ingest cheap:
without it, three forked subtasks per request would mean three
platform-thread-pool threads per request under load.

## Deferred, not adopted

**JEP 517 (HTTP/3 for the HTTP Client API, final in 26)** is the cheapest
way to add a second final-in-26 feature if there's time left after the core
path is done, pulling an official reference air-quality station over
HTTP/3 also answers this project's own "SEN54 is a proxy, not lab-grade"
caveat. Declined for now; revisit only if there's slack.

**JEP 524 (PEM Encodings)** for signed node identity and **JEP 529 (Vector
API)** for SIMD-accelerated re-baselining were both considered and
declined: real ideas worth having on record, just not ones this project
needed yet.

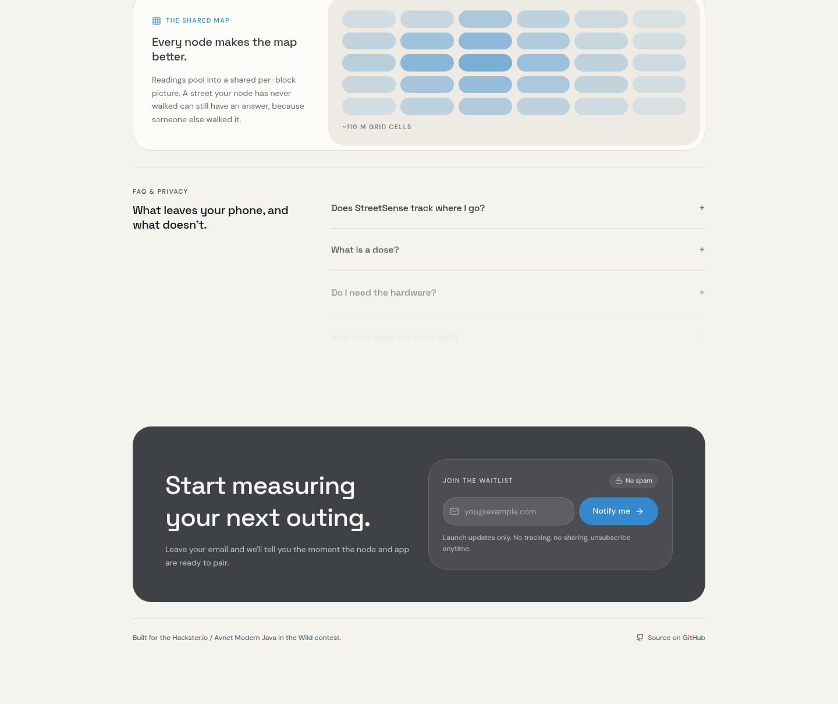
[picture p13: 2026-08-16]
docs/images/landing_page_shared_map.png

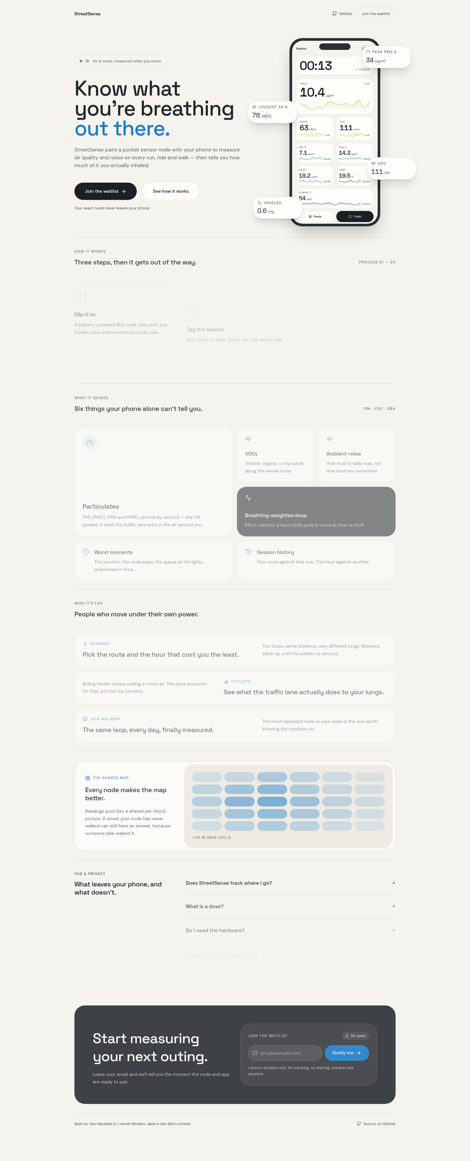
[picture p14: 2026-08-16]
docs/images/landing_page_full.png

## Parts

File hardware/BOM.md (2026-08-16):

# Bill of Materials

Prices are approximate USD list prices at time of writing, not live quotes,
check current pricing before ordering.

| Item | Qty | Approx. price | Notes |
| --- | --- | --- | --- |
| [Adafruit LED Glasses Driver, nRF52840](https://www.adafruit.com/product/5217) | 1 | ~$25 | The sensor node's MCU + BLE radio. Onboard LIS3DH accelerometer (not a full IMU) and PDM digital microphone; STEMMA QT port. |
| Sensirion SEN54 (PM + VOC + temp/RH) | 1 | ~$40 | Verified against physical hardware (`ledglasses_sen54` environment). Connects via STEMMA QT / Qwiic-compatible I2C. |
| [Adafruit SEN5x STEMMA QT adapter breakout](https://www.adafruit.com/product/5964) | 1 | ~$3 | Breaks the SEN54's JST-GH connector out to STEMMA QT so it can share the driver board's I2C bus. |
| [Adafruit MAX17048 fuel gauge](https://www.adafruit.com/product/5580) | 1 | ~$7 | Battery voltage, state of charge, and charge rate. Shares the I2C bus with the SEN54 at a different address (0x36 vs 0x69). |
| STEMMA QT / Qwiic cable (JST-SH 4-pin) | 2 | ~$1 each | One for the SEN54 adapter, one for the MAX17048 breakout, both off the driver board's STEMMA QT port (or daisy-chained off each other). |
| LiPo battery, 3.7V, 2500 mAh | 1 | ~$10 to $15 | Sized for the trade a clip-on wearable actually needs: enough capacity to cover a long outing without a mid-run recharge, light enough to still be worth clipping on. The driver board has an onboard JST battery connector and charge circuit; the MAX17048 needs to be wired across the same cell (its own JST-PH is not the same physical connection as the driver board's) to report real charge state. |
| Android phone (physical device, API 31+) | 1 | n/a | BLE central; BLE does not work in the emulator. User-supplied. |

## Enclosure

3D printed, designed in Onshape alongside the internal layout. Source file:
[`Case v2.3mf`](Case%20v2.3mf). Separate openings for the SEN54's air inlet
and fan outlet, kept apart per Sensirion's own design guidance so outgoing
air isn't drawn straight back into the inlet.

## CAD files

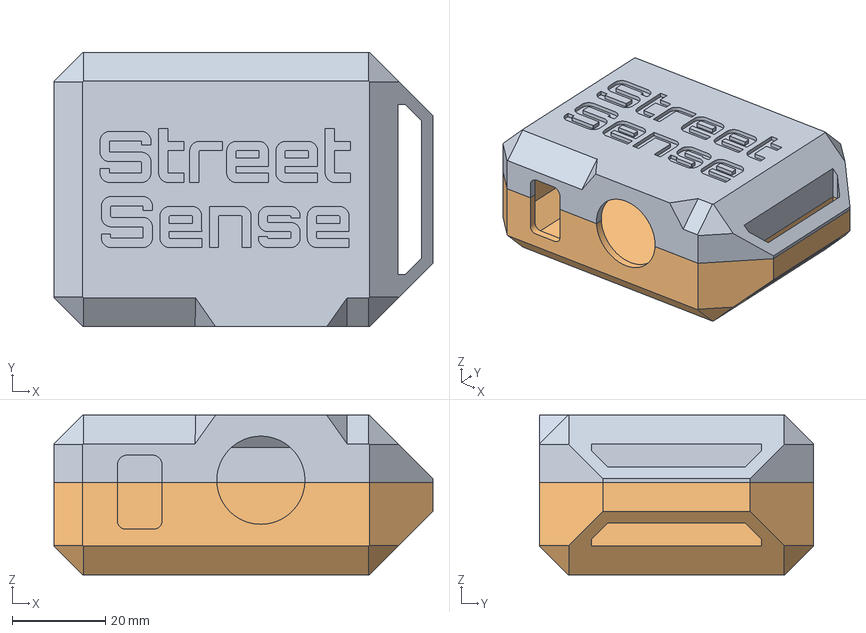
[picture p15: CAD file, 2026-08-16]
hardware/Case v2.3mf
81.5 x 59.0 x 34.4 mm

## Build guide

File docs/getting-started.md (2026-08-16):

# Getting started

Each part of StreetSense has a one command runner script in
[`scripts/`](../scripts/), and the full commands behind them are in
[`docs/quickstart.md`](quickstart.md).

```sh
scripts/run-backend.sh    # backend, http://localhost:8080
scripts/run-firmware.sh   # firmware
scripts/run-app.sh        # app, needs a physical Android phone
```

The app needs a real phone rather than the emulator, since Bluetooth Low
Energy does not work in Android's emulator. See
[`docs/quickstart.md`](quickstart.md) for the full setup steps, including
pointing the app at a locally running backend.

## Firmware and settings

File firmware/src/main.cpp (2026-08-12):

#include <bluefruit.h>
#include "packet.h"
#include "ble_uuids.h"
#include "battery_monitor.h"

// Which sensor path gets compiled in is the only difference between the two
// ledglasses environments in platformio.ini. Everything downstream — the
// packet, the app, the backend — is identical either way; the mock flags
// itself on the wire via FLAG_MOCK_DATA.
#if defined(STREETSENSE_MOCK) && STREETSENSE_MOCK
#include "mock_sensor_source.h"
#else
#include "sen54_sensor_source.h"
#endif

namespace {
constexpr uint32_t NOTIFY_INTERVAL_MS = 1000;

// v2's 26-byte payload plus the 3-byte L2CAP/ATT header no longer fits the
// default 23-byte MTU (see packet.h) — BANDWIDTH_MAX negotiates up to 247.
constexpr uint16_t MIN_USABLE_MTU = sizeof(StreetSensePacket) + 3;

BLEService streetSenseService(STREETSENSE_SERVICE_UUID);
BLECharacteristic streetSenseChar(STREETSENSE_CHAR_UUID);
BLEDis deviceInfo;

#if defined(STREETSENSE_MOCK) && STREETSENSE_MOCK
MockSensorSource sensorSource;
#else
Sen54SensorSource sensorSource;
#endif

// The fuel gauge is real hardware on every build — mock and real
// environmental sources alike report genuine battery telemetry, since the
// physical battery is present regardless of which sensor path is compiled in.
BatteryMonitor batteryMonitor;

uint16_t sequence = 0;
uint32_t lastNotifyMs = 0;
bool loggedLowMtu = false;

void startAdvertising() {
    // The primary advertising packet is capped at 31 bytes. Flags (3B) +
    // TX power (3B) + a 128-bit service UUID (18B) already use 24 of them,
    // leaving only 7 — enough for a 5-character name ("Stree"), silently
    // truncating "StreetSense-01". The full name goes in the scan response
    // packet instead, which has its own separate 31-byte budget.
    Bluefruit.Advertising.addFlags(BLE_GAP_ADV_FLAGS_LE_ONLY_GENERAL_DISC_MODE);
    Bluefruit.Advertising.addTxPower();
    Bluefruit.Advertising.addService(streetSenseService);
    Bluefruit.ScanResponse.addName();

    Bluefruit.Advertising.restartOnDisconnect(true);
    Bluefruit.Advertising.setInterval(32, 244); // in units of 0.625ms
    Bluefruit.Advertising.setFastTimeout(30);
    Bluefruit.Advertising.start(0); // 0 = advertise indefinitely
}
} // namespace

void setup() {
    Serial.begin(115200);

    // Deliberately not fatal. If the SEN54 is unplugged or the mic won't
    // start, the node still advertises and stays connectable — it simply
    // never notifies, because read() keeps returning false. A node that
    // vanishes from the air is much harder to diagnose in the field than one
    // that is present but silent.
    if (!sensorSource.begin()) {
        Serial.println("sensor source failed to start — no packets will be sent");
    }

    // Same non-fatal treatment: a missing/unresponsive fuel gauge just means
    // every packet goes out with FLAG_BATTERY_VALID clear, not silence.
    if (!batteryMonitor.begin()) {
        Serial.println("battery monitor failed to start — packets will carry no battery data");
    }

    // Must precede Bluefruit.begin() — it sizes the SoftDevice's connection
    // configuration, which begin() locks in.
    Bluefruit.configPrphBandwidth(BANDWIDTH_MAX);

    Bluefruit.begin();
    Bluefruit.setTxPower(4);
    Bluefruit.setName("StreetSense-01");

    deviceInfo.setManufacturer("Adafruit Industries");
    deviceInfo.setModel("LED Glasses Driver nRF52840");
    deviceInfo.begin();

    // NOTE: BLEService::begin() must be called before adding its
    // characteristics — characteristics attach to the most recently
    // begun service. Get this order wrong and the characteristic silently
    // attaches to the wrong (or no) service.
    streetSenseService.begin();

    streetSenseChar.setProperties(CHR_PROPS_NOTIFY);
    streetSenseChar.setPermission(SECMODE_OPEN, SECMODE_NO_ACCESS);
    streetSenseChar.setFixedLen(sizeof(StreetSensePacket));
    streetSenseChar.begin();

    startAdvertising();
}

void loop() {
    uint32_t now = millis();
    if (now - lastNotifyMs < NOTIFY_INTERVAL_MS) {
        return;
    }
    lastNotifyMs = now;

    Reading reading;
    if (!sensorSource.read(reading)) {
        return;
    }

    BatteryMonitor::Status battery;
    if (batteryMonitor.read(battery)) {
        reading.battery_valid = true;
        reading.charging = battery.charging;
        reading.battery_volts = battery.volts;
        reading.battery_soc = battery.soc_percent;
        reading.battery_rate = battery.rate_percent_per_hour;
    }

    StreetSensePacket packet;
    encode_packet(reading, sequence++, packet);

    uint8_t buf[sizeof(StreetSensePacket)];
    write_packet_bytes(packet, buf);

    if (Bluefruit.connected() && streetSenseChar.notifyEnabled()) {
        uint16_t connHdl = Bluefruit.connHandle();
        uint16_t mtu = Bluefruit.Connection(connHdl)->getMtu();
        if (mtu < MIN_USABLE_MTU && !loggedLowMtu) {
            loggedLowMtu = true;
            Serial.printf("warning: central negotiated MTU %u, packet needs %u — "
                           "notify will truncate\n", mtu, MIN_USABLE_MTU);
        }
        streetSenseChar.notify(buf, sizeof(buf));
    }
}

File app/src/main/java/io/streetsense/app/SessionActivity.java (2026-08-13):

package io.streetsense.app;

import android.content.Intent;
import android.os.Bundle;
import android.os.Handler;
import android.os.Looper;
import android.view.View;
import android.widget.ImageView;
import android.widget.LinearLayout;
import android.widget.ProgressBar;
import android.widget.TextView;

import androidx.appcompat.app.AppCompatActivity;

import com.google.android.material.button.MaterialButton;
import com.google.android.material.card.MaterialCardView;

import org.osmdroid.config.Configuration;
import org.osmdroid.tileprovider.tilesource.TileSourceFactory;
import org.osmdroid.views.MapView;

import java.util.ArrayList;
import java.util.List;
import java.util.Locale;

import io.streetsense.app.metrics.Band;
import io.streetsense.app.metrics.Metric;
import io.streetsense.app.session.SessionController;
import io.streetsense.app.session.TracePoint;
import io.streetsense.app.ui.RouteMapRenderer;
import io.streetsense.app.ui.SparklineView;
import io.streetsense.app.ui.TopBar;

/**
 * Screen 3 — live readings while a session is recording. See
 * docs/handoff/screens.md #3. Route guard: if the session isn't running and
 * the module isn't connected, this screen bounces back to Connect.
 */
public final class SessionActivity extends AppCompatActivity implements SessionController.Listener {

    private static final int SPARKLINE_POINTS = 40;

    private record CompactCard(View root, TextView value, SparklineView sparkline, TextView band, Metric metric) {}

    private TextView timerText;
    private View runStatusDot;
    private TextView runStatusLabel;

    private MaterialCardView bannerCard;
    private ImageView bannerIcon;
    private ProgressBar bannerSpinner;
    private TextView bannerTitle;
    private TextView bannerDetail;
    private TextView bannerAction;

    private LinearLayout readingsColumn;
    private View readingsSkeleton;

    private View heroCard;
    private TextView heroBand;
    private TextView heroValue;
    private TextView heroUnit;
    private SparklineView heroSparkline;

    private View noiseCard;
    private TextView noiseValue;
    private TextView noiseUnit;
    private SparklineView noiseSparkline;
    private TextView noiseBand;

    private View vocCard;
    private TextView vocValue;
    private SparklineView vocSparkline;
    private TextView vocBand;

    private CompactCard[] compactCards;

    private MaterialCardView routeMapCard;
    private MapView routeMap;
    private TextView mapPillPm25;
    private TextView mapPillPm10;
    private TextView mapPillNoise;
    private Metric mapColorBy = Metric.PM25;

    private MaterialButton pauseResumeButton;
    private MaterialButton finishButton;

    private final Handler tickHandler = new Handler(Looper.getMainLooper());
    private final Runnable tick = new Runnable() {
        @Override
        public void run() {
            renderTimer();
            tickHandler.postDelayed(this, 1000);
        }
    };

    @Override
    protected void onCreate(Bundle savedInstanceState) {
        Configuration.getInstance().load(getApplicationContext(), getPreferences(MODE_PRIVATE));
        Configuration.getInstance().setUserAgentValue(getPackageName());
        super.onCreate(savedInstanceState);
        setContentView(R.layout.activity_session);

        io.streetsense.app.ui.EdgeInsets.apply(findViewById(R.id.root),
                findViewById(R.id.scrollContent), findViewById(R.id.bottomBar));

        View topBar = findViewById(R.id.topBar);
        ((TextView) topBar.findViewById(R.id.topBarTitle)).setText(R.string.session_title);

        timerText = findViewById(R.id.timerText);
        runStatusDot = findViewById(R.id.runStatusDot);
        runStatusLabel = findViewById(R.id.runStatusLabel);

        bannerCard = findViewById(R.id.bannerCard);
        bannerIcon = findViewById(R.id.bannerIcon);
        bannerSpinner = findViewById(R.id.bannerSpinner);
        bannerTitle = findViewById(R.id.bannerTitle);
        bannerDetail = findViewById(R.id.bannerDetail);
        bannerAction = findViewById(R.id.bannerAction);
        bannerAction.setOnClickListener(v -> controller().retry());

        readingsColumn = findViewById(R.id.readingsColumn);
        readingsSkeleton = findViewById(R.id.readingsSkeleton);

        heroCard = findViewById(R.id.heroCard);
        heroBand = findViewById(R.id.heroBand);
        heroValue = findViewById(R.id.heroValue);
        heroUnit = findViewById(R.id.heroUnit);
        heroSparkline = findViewById(R.id.heroSparkline);
        heroCard.setOnClickListener(v -> openMetricSheet(Metric.PM25));

        noiseCard = findViewById(R.id.noiseCard);
        noiseValue = findViewById(R.id.noiseValue);
        noiseUnit = findViewById(R.id.noiseUnit);
        noiseSparkline = findViewById(R.id.noiseSparkline);
        noiseBand = findViewById(R.id.noiseBand);
        noiseCard.setOnClickListener(v -> openMetricSheet(Metric.NOISE));

        vocCard = findViewById(R.id.vocCard);
        vocValue = findViewById(R.id.vocValue);
        vocSparkline = findViewById(R.id.vocSparkline);
        vocBand = findViewById(R.id.vocBand);
        vocCard.setOnClickListener(v -> openMetricSheet(Metric.VOC));

        compactCards = new CompactCard[]{
                bindCompactCard(R.id.pm1Card, Metric.PM1),
                bindCompactCard(R.id.pm4Card, Metric.PM4),
                bindCompactCard(R.id.pm10Card, Metric.PM10),
                bindCompactCard(R.id.tempCard, Metric.TEMP),
                bindCompactCard(R.id.humidityCard, Metric.HUMIDITY),
        };

        routeMapCard = findViewById(R.id.routeMapCard);
        routeMap = findViewById(R.id.routeMap);
        routeMap.setTileSource(TileSourceFactory.MAPNIK);
        routeMap.setMultiTouchControls(true);
        routeMapCard.getViewTreeObserver().addOnGlobalLayoutListener(() -> {
            int width = routeMapCard.getWidth();
            int targetHeight = width * 10 / 16;
            if (width > 0 && routeMapCard.getLayoutParams().height != targetHeight) {
                routeMapCard.getLayoutParams().height = targetHeight;
                routeMapCard.requestLayout();
            }
        });

        mapPillPm25 = findViewById(R.id.mapPillPm25);
        mapPillPm10 = findViewById(R.id.mapPillPm10);
        mapPillNoise = findViewById(R.id.mapPillNoise);
        mapPillPm25.setOnClickListener(v -> setMapColorBy(Metric.PM25));
        mapPillPm10.setOnClickListener(v -> setMapColorBy(Metric.PM10));
        mapPillNoise.setOnClickListener(v -> setMapColorBy(Metric.NOISE));
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

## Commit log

2026-08-03 Slice 1: repo skeleton, mocked BLE firmware, Android app, Java 26 backend
    Wires the full StreetSense path end-to-end with mocked sensor data:
    - firmware/: PlatformIO project for the Adafruit LED Glasses Driver
    (nRF52840). Custom 128-bit GATT service notifies a packed 20-byte
    StreetSensePacket at 1Hz via a bounded-random-walk mock sensor source.
    Native Unity tests (including a golden byte-vector check) pass, and the
    firmware is flashed and verified live over BLE via tools/ble_sniff.py.
    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
2026-08-03 Make the Android app buildable and actually able to upload
    First real compile of /app — it was written blind against a machine with no
    Android SDK. Building it surfaced one blocker and several defects that would
    have made the end-to-end test fail or, worse, silently do nothing.
    Build:
    - compileSdk 36 -> 37. Only android-37.0 is installed locally and there's no
    cmdline-tools to fetch 36; 37 is also AGP 9.3.1's highest supported API.
    targetSdk stays at 36 (just a manifest number, needs no platform).
    Uploads would essentially never have fired:
    - LocationTagger issued a one-shot getCurrentLocation per packet, at 1Hz,
    cancelling its own in-flight request each time. A fix takes far longe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
2026-08-03 firmware: implement real SEN54 sensor path, give mock distinguishable excursions
    Sen54SensorSource now reads PM/VOC/temp/humidity from Sensirion's own
    I2C driver, plus a new PdmNoiseMeter for the onboard microphone. Not
    yet run against physical hardware (SEN54 is committed to another
    project) — ledglasses_sen54 compiles but is unverified; ledglasses
    (the default) stays on the mock.
    The mock's only excursion used to raise PM, VOC and noise together,
    so the backend's upcoming event classifier would have had exactly one
    signature to classify against, and both the tests and the demo would
    have looked fine while proving nothing. It now rotates through four
    distinct shapes (PM alone, PM+VOC, VO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
    [main.cpp]
2026-08-03 app: snap to grid cell before upload, add session recording
    The precise GPS fix used to be uploaded verbatim. It now never leaves
    the device: ReadingUploader snaps to a ~110m GridCell (mirrored from
    the backend's own, with a golden-coordinate test on each side so the
    two can't silently drift apart) and only the bucket pair is sent. The
    precise trace goes into SessionRecorder's local-only TracePoint list
    instead, for the session map.
    A random per-install ContributorId is added so the backend's crowd
    layer can count distinct contributors rather than readings — not a
    device or account identifier, so it correlates with nothing else.
    MainActivity gets a SessionRecorder wired in; a Run/Cycle/W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
2026-08-03 backend: cells not traces, hour-keyed baselines, explained anomaly events
    Three changes to the core domain that turned out to depend on each
    other closely enough to land together:
    Privacy split. DecodedReading no longer has a lat/lon field to receive
    one into — GridCell retunes from ~1.1km to ~110m (a real trade: fine
    enough to tell one street from the next, coarse enough that a cell
    names a block, not a building) and the ingest path takes latBucket/
    lonBucket instead of coordinates. A pre-split client posting lat/lon
    gets a 400, not a silent re-snap.
    Hour-keyed cells. CellKey(cell, hourOfDay) replaces GridCell as the
    baseline's key — a street at 07:00 and at 18:00 are different places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
2026-08-03 backend: session debrief with inhaled dose and worst-segment lookup
    The distinctive number the whole product rests on: identical air costs
    a runner several times what it costs someone walking a dog through it,
    because ventilation rate rises with exertion, and no fitness watch
    reports that. DoseGatherer folds a session's readings into inhaled
    micrograms (concentration x resting ventilation x activity multiplier
    x elapsed time), measuring real gaps between capture timestamps rather
    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
2026-08-03 backend: crowd layer — pool contributions, cleanest/quietest hour
    The actual network effect, and it's demonstrable at two contributors:
    a block your own node has never visited gets an answer, because
    someone else walked it. CrowdService pools every contributor's
    readings per cell and reports cleanest-hour and quietest-hour
    separately, since a street can be quiet at the exact hour it's
    dirtiest.
    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
2026-08-03 docs: reflect sessions, crowd layer, and the sensor honesty caveats
    Brings honest-caveats.md, java26-jeps.md and future-work.md in line
    with what the last five commits actually built, rather than letting
    the docs describe slice 1 while the code has moved on:
    - PDM noise readings are an uncalibrated, unweighted estimate, not
    certified dB(A) — documented alongside the same reasoning already
    in the code (pdm_noise_meter.h).
    - Classification is rule-based over sensor cross-products, still not
    a trained model, now producing an explained diagnosis rather than a
    bare severity.
    - Dose is a population-level ventilation estimate for comparing
    sessions, not a personal intake measurement.
    -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
2026-08-03 app: session UI — activity picker, dose/event debrief with route map
    Start now asks Run/Cycle/Walk before scanning, since that choice is
    what turns a concentration into the debrief's headline dose number.
    Stop hands the finished session's local trace to a new
    SessionDebriefActivity via TraceCache (an in-memory single-slot
    handoff, not an Intent extra — a multi-minute 1Hz session's point list
    can approach the ~1MB Binder transaction limit).
    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
2026-08-03 backend: dashboard served from the Java tier, live over SSE
    One deployable, not two: the dashboard is static assets under
    src/main/resources/static, served by the same Java 26 process that
    does everything else, with a GET /api/v1/stream endpoint pushing every
    ingested reading to open browser tabs. SseEmitter over the virtual
    threads already enabled for ingest — a long-held SSE connection is one
    blocked thread per browser tab, which is exactly what virtual threads
    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
2026-08-03 docs: rewrite README for Best Health, fix stale protocol/BOM claims
    README now leads with the actual product — sessions, dose, the crowd
    layer, cells-not-traces — and claims Best Health Solution rather than
    Best Home, matching the category decisions already made. Quickstart
    updated for the real firmware environments (ledglasses = mock/default,
    ledglasses_sen54 = real, unverified), the dashboard being backend-served
    at localhost:8080 with an optional seeding flag, and the app's
    session/debrief/history flow rather than the old single-screen Start/Stop.
    Two claims elsewhere had gone stale as the code moved past them:
    ble-protocol.md still said the phone forwards GPS (it forwards a grid
    cel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
2026-08-04 ui: design system pass on dashboard + Android app
    Dashboard: cells now render as true pixel-squares (Mercator-corrected
    divIcon markers, resized on zoomend) instead of lat/lon-bound
    rectangles that skewed non-square off the equator. Adds a small CSS
    type scale on top of the existing custom-property palette.
    Android: first real design system for the app — Material 3 theme and
    colors.xml/values-night ported from the dashboard's palette, replacing
    the unstyled default MaterialComponents theme, hardcoded color
    literals, bare AlertDialog picker, stock ListView history screen, and
    plain TextView event rows. Adds a custom adaptive launcher icon
    (cells glyph) with a monochrome variant, replacing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
2026-08-04 tooling: one-command scripts to run each module
    Collapses each module's multi-step Quickstart (pio env flags, gradle
    --enable-preview, adb bootstrap dance) into scripts/run-{backend,firmware,app}.sh,
    plus a matching .claude/skills/run so Claude sessions launch things the same
    way. backend/build.gradle.kts gets a small -Pseed=true passthrough since
    Gradle's bootRun has no built-in equivalent to the Spring Boot Maven plugin's
    -Dspring-boot.run.jvmArguments convention.
2026-08-12 refactor(firmware): PlatformIO-conventional layout
    Only main.cpp belongs in src/ per PlatformIO convention. Move every
    sensor source and shared header into lib/ as private libraries (or
    include/ for the project-wide UUID header), and let the Library
    Dependency Finder resolve them from the #include chain instead of
    compiling everything in src/ unconditionally.
    This also drops the test_build_src/build_src_filter hack in
    [env:native] — with nothing but main.cpp in src/, the LDF now
    resolves the native tests' dependencies (mock_sensor_source,
    sensor_source, streetsense_packet) on its own, and [env:ledglasses]
    no longer compiles sen54_sensor_source.cpp at all since main.cpp
    never reaches it in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
2026-08-12 feat(firmware): MAX17048 battery monitor
    Adds a BatteryMonitor library wrapping Adafruit's MAX1704X driver for
    the 5580 fuel gauge breakout, sharing the I2C bus with the SEN54 at a
    different address (0x36 vs 0x69). Peer to SensorSource rather than an
    implementation of it, since battery is orthogonal to the environmental
    channels — composed alongside whichever SensorSource main.cpp is
    using, so even the mock build reports real battery data.
    The nRF52840 has no charger-status pin on this driver board, so
    "charging" is inferred: USB VBUS present AND the gauge's own charge
    rate is positive (with a small epsilon to avoid flicker near zero).
    Not yet wired into main.cpp or the wire format — th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
2026-08-12 feat(protocol): v2 packet with battery fields
    Grows StreetSensePacket from 20 to 26 bytes: version bumps to 2, two
    new flag bits (CHARGING, BATTERY_VALID), and three new fields
    (batt_mv, batt_soc x10, batt_rate x10 signed %/hr). This spends the
    MTU negotiation the 20-byte format was originally sized to avoid —
    main.cpp now calls configPrphBandwidth(BANDWIDTH_MAX) before
    Bluefruit.begin() and warns once if a central negotiates below the
    26+3 bytes the packet needs.
    main.cpp composes BatteryMonitor's reading onto whichever
    SensorSource is active (mock or SEN54) every tick; a gauge that never
    started leaves FLAG_BATTERY_VALID clear and the battery fields
    zeroed, following the same "present b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
    [main.cpp]
2026-08-12 feat(app,backend): decode v2 packet, surface battery
    PacketLayout.decode() is now version-aware: it accepts both the
    20-byte v1 layout and the 26-byte v2 layout (dispatching on length,
    with the version byte still exposed), decoding battery fields only
    when FLAG_BATTERY_VALID is set. DecodedPacket grows a nested
    BatteryStatus record with an ABSENT constant and keeps its old 11-arg
    constructor as a delegating overload, so the dozen existing v1 call
    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
2026-08-12 docs: v2 protocol and battery telemetry
    Documents the v2 wire format (26 bytes, MTU negotiation, battery
    fields and the VBUS+charge-rate charging inference), adds the v2
    golden packet fixture alongside the v1 one for backward-compat
    reference, lists the new MAX1704X/BusIO dependencies in
    docs/attribution.md, and adds the MAX17048 breakout + SEN5x adapter
    + second STEMMA QT cable to the BOM with a note on wiring the gauge
    across the same cell the driver board draws from.
    Leaves the SEN54-unverified language in README.md and future-work.md
    alone pending the hardware verification pass in the next commit.
2026-08-12 docs+fix: hardware verification pass
    Flashed env:ledglasses_sen54 to the attached board (Adafruit LED
    Glasses Driver nRF52840 + SEN54 on the 5964 adapter + MAX17048 fuel
    gauge on 5580) and confirmed real end-to-end reception with
    firmware/tools/ble_sniff.py: steady 26-byte v2 notifications at 1 Hz,
    version 2, mock false, monotonically increasing seq, plausible SEN54
    readings, and valid non-mock battery telemetry (3.893 V / 63.5% SoC).
    Updates README.md and hardware/BOM.md to say so instead of "not yet
    run on hardware."
    Also corrects an inaccurate platformio.ini comment from the layout
    refactor: PlatformIO's LDF "chain" mode textually scans #include
    lines without evaluating main.cpp's #ifdef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
2026-08-13 feat(app,backend): decode PM1/PM4/PM10, add DRIVING activity
    The redesigned UI surfaces all four PM channels (previously only PM2.5
    was decoded — the others were already on the wire and in the backend,
    just discarded by the app) and a fourth activity option with no prior
    backend equivalent, so it needs its own ventilation multiplier.
2026-08-13 feat(app): design-system tokens, fonts, icons, shared components
    New flat/rounded visual language from the Lovable handoff: light+dark
    color tokens and air-quality band colors, DM Sans + Space Grotesk
    (downloaded from Google's open-source font repo, bundled as variable
    fonts), the type scale, card/inset-well/button widget styles, a Lucide-
    derived icon set converted to vector drawables, and the reusable pieces
    every screen needs (battery pill, sparkline, area chart, route map
    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
2026-08-13 feat(app): redesign UI — activity select, connect, session, summary
    Replaces the single-screen app with the four-screen flow from the
    Lovable handoff: Activity select -> Connect -> Session -> Summary, plus
    a metric detail bottom sheet. SessionController (held by the new
    StreetSenseApp) is the single observable session/BLE state shared
    across screens, so the module connection survives navigating between
    them. Bluetooth-off and permission-denied states reuse Connect's own
    error-card pattern, since the handoff mock didn't design for them.
    The old History and dose/event Debrief screens are dropped per this
    being a full replace of the flow; Summary now computes its numbers
    locally from the ses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
    [SessionActivity.java]
2026-08-13 fix(app): edge-to-edge insets and dark-mode icon contrast
    Applies EdgeInsets.apply() across the four redesigned screens so
    content and bottom-bar padding respect system bars, and fixes low
    icon contrast on the activity-selection screen in dark mode.
    [SessionActivity.java]
2026-08-13 feat(backend): add request correlation and web-layer logging
    CorrelationIdFilter tags every request's log lines with a requestId
    (echoed back via X-Request-Id) so a client-reported issue can be
    traced through whichever controllers and services it touched.
    Controllers and the SSE broadcaster log their key lifecycle events —
    submissions, malformed-request rejections, cell/session lookups, and
    live-feed subscribe/publish activity.
2026-08-13 feat(backend): log ingest lifecycle with MDC-bound correlation ID
    MDC is populated before the structured-concurrency fork so every
    subtask (persist, baseline update, anomaly check) inherits the same
    correlationId, letting one ingest's log lines be traced together
    even though the work fans out across threads. Non-normal verdicts
    log at INFO since they're the events worth noticing; routine ingests
    stay at DEBUG.
2026-08-13 feat(backend): log rolling baseline updates
    DEBUG-level, since this fires on every ingest — useful for watching
    a specific cell's baseline drift during tuning without being noisy
    by default.
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2026-08-16 docs: add sensor node enclosure render and source file
    Add the Onshape render of the 3D printed case to the Sensor node
    section, showing the SEN54's separate air inlet and fan outlet
    openings, kept apart per Sensirion's own design guidance. Add the
    case's source file and update the BOM, which previously said the
    enclosure wasn't sourced yet.
    [Case v2.3mf]
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2026-08-16 feat(backend): add idempotent contributor eviction to the repository
    ReadingRepository.evictWhere(Predicate<String>) removes every stored
    reading whose contributor id matches, from every index (byId,
    insertion order, per-session, and per-cell-hour). Takes a predicate
    rather than depending on CrowdService.isSeeded() directly, so the
    repository layer doesn't need to know what "seeded" means — the
    caller decides.
    Not wired up yet; the next commit uses it to make re-seeding around a
    new location idempotent.
2026-08-16 feat(dashboard): redesign as fullscreen branded map with cell detail panel
    Brings the dashboard from a bare dev tool up to the same product bar
    as the Android app and landing page:
    - Fullscreen Leaflet map (CARTO light/dark basemaps) with floating
    overlay chrome (header, stat tiles, legend, collapsible live feed)
    instead of a 420px map card boxed in next to a feed panel.
    - Design tokens ported from the app's design system: warm cream/
    near-black/blue palette, Space Grotesk + DM Sans (vendored locally
    as the exact files already bundled in the Android app, not a Google
    Fonts CDN link — a client demo shouldn't depend on reaching
    fonts.googleapis.com), flat bordered cards, stadium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
2026-08-16 fix(dashboard): clamp the hero chart tooltip within the panel bounds
    The tooltip was centered on the cursor via left:X% + translate(-50%),
    with #cellPanel clipping anything that overflowed. Confirmed: hovering
    the last ~15% of the 24h chart — including the "latest reading"
    end-cap, the point people most want to check — pushed the tooltip
    past the panel's right edge and truncated the text mid-word.
    Now computed as a clamped pixel offset (Math.min/max against the
    chart's actual rendered width) so it can't be pushed past either edge
    regardless of its own (text-dependent) width. Also sets
    .panel-body{overflow-x:hidden} as a second line of defense against any
    future absolutely-positioned ele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
2026-08-16 fix(dashboard): label map cell markers for assistive tech
    Leaflet auto-assigns role="button" tabindex="0" to interactive
    markers but no accessible name — confirmed via the a11y tree, a
    screen reader hit 80+ identical, indistinguishable "button"s with no
    way to tell them apart. The map is the product here, so this matters
    more than a typical icon-button label gap.
    Every marker now carries an aria-label like "Cell 49018, 8409:
    14.1 µg/m³ PM2.5, corroborated", refreshed on both the initial-render
    and in-place-update paths.
2026-08-16 fix(dashboard): meet the 44px minimum touch target on controls
    --min-touch: 44px was already ported from the app's own design system
    but never actually applied — the theme toggle and panel close button
    measured 36x36, the live-feed toggle/collapse pills 24px tall, and
    Leaflet's zoom buttons 30x30. All four now hit 44px, measured.
2026-08-16 fix(dashboard): apply the brand accent to links and focus rings
    --accent (#0F74C5 / #4C9DEB) was ported as a token but never actually
    used anywhere — grepped both files, it appeared only in its own
    declaration. The one color that carries the brand's identity on the
    landing page and app didn't appear anywhere in the dashboard's UI.
    Now drives link color and an explicit :focus-visible outline, the
    latter also giving keyboard navigation a real focus indicator where
    previously there was only the browser default against a blurred,
    translucent overlay background.
2026-08-16 fix(grid): make longitude bucketing produce square cells, not just latitude
    A GridCell bucketed latitude and longitude at the same flat 0.001°,
    but longitude compresses toward the poles while latitude doesn't —
    so cells were narrower east-west than north-south almost everywhere
    off the equator, and Mercator (being conformal) rendered that
    distortion faithfully rather than hiding it.
    The longitude step now widens by 1/cos(latitude), resolved per ~11km
    band of latitude rather than per individual row: a lonBucket is a
    large integer counted from the prime meridian, and multiplying that
    by a step that changes every row would turn cos(latitude)'s per-row
    floating-point drift into a visible off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
2026-08-16 fix(dashboard): stop grid tiles from painting over the basemap
    Cell fills used a flat CSS opacity on the whole marker div, so at 0.75
    for corroborated cells (the common case) a gapless grid tiled
    edge-to-edge into a solid coat over the streets underneath. Move the
    alpha into the fill's own rgba() instead, drop the max well below 1,
    and stop the confidence border riding along with it.
    Corroborated cells also carried a bold black-in-light/white-in-dark
    outline that, applied to most of the grid, read as a harsh
    graph-paper overlay. They now use the app's own hairline --border
    token; single-contributor stays dashed and visible since that's the
    data actually worth flagging as provisional.
    Also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
2026-08-16 feat(seed): replace radiating-arm demo shape with a full-coverage crowd mask
    The old seeder walked a handful of road-like corridors out from a solid
    core, which read as sparse and geometric rather than like a real
    crowd-sourced heatmap. Replaced it with a single deterministic mask —
    near-total coverage with scattered gaps, block-correlated patchy
    intensity, and a few isolated hot/cool outlier cells — computed as
    offsets from the seeded center so the same shape reproduces every run
    and just translates wherever it's centered, instead of reshuffling.
    Also rescaled the map's sequential ramp (PM_SCALE_MAX 100 -> 20 ug/m3)
    so the seeded data's actual range spreads across the ramp instead of
    r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
2026-08-16 fix(seed): seed once at startup, stop reseeding on every dashboard load
    The dashboard fired a fire-and-forget POST /api/v1/seed on every load
    to recenter demo data on the visitor's geolocation, racing the
    immediate /api/v1/cells fetch. A reseed evicted the old data and took
    ~6.7s to rewrite, and since ContributorSeeder never published SSE
    events, the page had no way to catch up once it lost that race —
    leaving the dashboard empty until another reload repeated it.
    Drop the reload-triggered reseed entirely: seeding only ever happens
    once, at boot, via ApplicationRunner. Removes the now-dead
    SeedController, ContributorSeeder.seedAround()/distance-jitter guard,
    and ReadingRepository.evictWher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
